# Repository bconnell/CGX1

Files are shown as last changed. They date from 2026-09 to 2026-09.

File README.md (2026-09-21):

<div align="center">

# CGX 1

### Compact GPU Engineering Design

**167.5 mm card length · 72 GB HBM4 baseline · 6.6 TB/s target bandwidth · 143.36 TFLOPS target · 360 W dock mode**

[Engineering Specification](docs/ENGINEERING_SPEC.md) · [ISA](docs/ISA.md) · [Graphics Pipeline](docs/GRAPHICS_PIPELINE.md) · [Documentation Index](docs/README.md) · [Validation](docs/VALIDATION.md)

**Design Engineer:** [Brandon Connell](https://github.com/bconnell) · [LinkedIn](https://www.linkedin.com/in/brandon-c-b317a81b/) · [Email](mailto:brandon@brandonconnell.com)  
Copyright © 2026 Brandon Connell · [MIT License](LICENSE)

</div>

CGX 1 is a compact desktop GPU architecture built around a low profile, dual slot card and an external power and thermal dock. The design targets graphics, game development, 3D work, media processing, compute, and local AI workloads while remaining usable in hosts that cannot supply or remove full GPU power internally.

> **Current status:** Engineering architecture and prototype design. No CGX 1 ASIC has been fabricated. Target values are analytical design values unless a document explicitly identifies measured prototype data. See [Project Status](docs/STATUS.md).

> **Repository policy:** CGX 1 is published as a public engineering reference. This repository does **not** accept pull requests, issues, discussions, external patches, or other community contributions. The MIT license permits independent forks and derivative work, but those remain separate projects unless Brandon Connell explicitly incorporates a change. For work inquiries or a serious private security concern, use the contact information in [AUTHORS.md](AUTHORS.md).

CGX 1 mechanical blueprint

[Open the mechanical blueprint directly](mechanical/cgx1_blueprint.svg)

## Design at a glance

| Parameter | Target | Design intent |
|---|---:|---|
| Card PCB | **167.5 × 68.5 mm** | Short, low profile board for compact desktop chassis |
| Installed thickness | **39.5 mm, dual slot** | Keep the installed card inside a conventional dual slot envelope |
| Baseline memory | **72 GB HBM4** | Two 36 GB stacks adjacent to the processor package |
| Peak memory bandwidth | **6.6 TB/s** | Aggregate architecture target from two 3.3 TB/s stacks |
| Peak FP32 | **143.36 TFLOPS** | Arithmetic target from lane count and 2.80 GHz peak clock |
| Full performance power | **360 W nominal** | External power and liquid cooling required |
| Standalone slot mode | **≤ 70 W** | Reduced operation without the external dock |
| Docked host slot draw | **≤ 25 W** | Keep high power demand off the host PSU |
| External supply | **48 V DC** | Certified AC/DC supply remains outside the coolant dock |
| PCIe target | **Gen 6 ×16** | Backward interoperability target through earlier PCIe generations |
| Dock envelope | **310 × 210 × 75 mm** | Sized around an actual 240 mm radiator, fans, pump/reservoir, fittings, and control hardware |

## Architecture

CGX 1 separates the compact add in card from the equipment needed for sustained high power operation. The card can boot and operate from the PCIe slot at a reduced power level. Full performance mode uses a rear connected 48 V power and liquid cooling dock, while mains conversion stays in a separate certified AC/DC supply.

```mermaid
flowchart LR
    AC[AC mains] --> PSU[Certified 48 V DC supply]
    PSU --> X[CGX 1 thermal dock]
    H[Host system] -->|PCIe x16| C[CGX 1 card]
    X -->|48 V + coolant| C
    C --> M[72 GB HBM4]
    C --> D[Display and media I/O]
```

The silicon target uses four compute tiles, a central I/O and cache die, two 36 GB HBM4 stacks, and a package level cache. The dock moves the radiator, pump, reservoir, and most full load heat rejection outside the host chassis.

## Operating modes

| Mode | Board limit | Host slot behavior | Use |
|---|---:|---:|---|
| **P0 Safe Boot** | 25 W | Up to 25 W | Reset, diagnostics, unknown host state, dock fault fallback |
| **P1 Slot Eco** | 45 W | Up to 45 W | Reduced slot powered operation on a qualified host |
| **P2 Slot Max** | 70 W | Up to 70 W | Maximum slot powered operation on a qualified host |
| **P3 Dock Quiet** | 220 W | ≤ 25 W | Development, capture, and moderate rendering |
| **P4 Dock Full** | 360 W | ≤ 25 W | Full design power target |
| **Transient ceiling** | 450 W | External path | Short electrical excursions, not sustained operation |

If dock power or valid coolant flow is lost in P3 or P4, the reference controller returns to **P0 Safe Boot** rather than increasing host slot demand.

## Primary design specification

[design/cgx1_architecture.json](design/cgx1_architecture.json) is the primary machine readable file for shared numeric targets. The repository validation scripts check important values mirrored in documentation, CAD, firmware, and the analytical model.

| Item | CGX 1 target | Notes |
|---|---:|---|
| Compute tiles | 4 | Separate graphics/compute tiles around the central I/O die |
| Compute units | 200 | 50 per tile |
| FP32 lanes | 25,600 | 128 per compute unit |
| Sustained clock target | 2.65 GHz | Full load design target |
| Peak clock target | 2.80 GHz | Used for peak FP32 arithmetic |
| Peak FP32 target | 143.36 TFLOPS | Not a measured benchmark |
| VRAM baseline | 72 GB HBM4 | Two 36 GB stacks |
| Future memory target | 96 GB HBM4 | Two 48 GB stacks if package and supply constraints permit |
| Package level cache target | 512 MB | Architecture target |
| Display target | 3 × Mini DisplayPort 2.1b + USB C DisplayPort Alt Mode | Final PHY and compliance work remains |
| Media target | 4 encode + 4 decode engines, AV1 | Architecture target |

## Architecture definition

The critical software-visible and multi-tile contracts are now defined rather than left to later RTL work:

| Area | Current architecture decision | Document |
|---|---|---|
| Execution | Native wave32; four SIMD32 partitions per CU; 32-bit base ISA with extension word | [ISA](docs/ISA.md) |
| Matrix engines | Four engines per CU; wave32; M16N16K16 FP16/BF16 and M16N16K32 FP8/INT8; fixed fragment map, 16-cycle issue target, staging/scoreboard RTL, signed INT8 arithmetic, integrated INT8 path, and a single-engine INT8 RTL shell | [Matrix Engine Architecture](docs/MATRIX_ENGINE.md) |
| Graphics | One logical GPU; 16 raster partitions; dynamic 32 × 32 pixel macro-tile ownership | [Graphics Pipeline](docs/GRAPHICS_PIPELINE.md) |
| Texture | 100 texture blocks; four bilinear samples/block/cycle arithmetic target | [Texture and Compression](docs/TEXTURE_COMPRESSION.md) |
| Compression | Lossless 256-byte surface blocks; no guaranteed compression ratio | [Texture and Compression](docs/TEXTURE_COMPRESSION.md) |
| Chiplet fabric | Central coherent I/O die; directory coherence; 7.2 TB/s aggregate read payload budget | [Chiplet Fabric](docs/CHIPLET_FABRIC.md) |
| Virtual memory | 57-bit GPU VA; 4 KiB/64 KiB/2 MiB pages; replayable faults; ATS/PASID optional | [Virtual Memory](docs/VIRTUAL_MEMORY.md) |
| Scheduling | 64 resident hardware queue contexts; 8 priorities; bounded preemption/reset escalation | [Scheduling and Preemption](docs/SCHEDULING_PREEMPTION.md) |
| Power management | Per-tile DVFS/power gating policy inside unchanged P0-P4 board limits; no fixed tile count per P-state | [Power Management](docs/POWER_MANAGEMENT.md) |

These values are design targets. They do not represent fabricated silicon capability or measured application performance.

## Prototype path

The first physical prototype does not require custom GPU silicon. **P0** is a dimensionally accurate electrothermal card and external dock used to validate fit, power distribution, coolant routing, control firmware, and a 360 W thermal load. **P1** adds a shared programmable HBM accelerator to the bench for PCIe, memory traffic, control, and software experiments.

| Stage | Hardware | What it establishes |
|---|---|---|
| **P0** | Card carrier, heaters, controller, cold plate, dock, instrumentation | Mechanical fit, 48 V delivery, cooling behavior, fault handling, firmware states |
| **P1** | P0 infrastructure plus an HBM capable programmable accelerator | PCIe behavior, memory traffic, host communication, selected RTL and software experiments |
| **Custom silicon** | Fabricated package and production class board | Device functionality, drivers, conformance, characterization, measured application performance |

See [Prototype Build](docs/PROTOTYPE_BUILD.md), [Mechanical Design](docs/MECHANICAL_DESIGN.md), and [Electrical Interface](docs/ELECTRICAL_INTERFACE.md).

## Documentation

The complete engineering document set is listed in the [Documentation Index](docs/README.md).

| Document | What it contains | Link |
|---|---|---|
| Engineering Specification | Card, package, silicon, memory, power, display, media, reliability | [Open](docs/ENGINEERING_SPEC.md) |
| ISA and Execution Model | Wave model, registers, instruction classes, memory ordering and faults | [Open](docs/ISA.md) |
| Matrix Engine Architecture | Numeric contract, physical tile shapes, wave32 fragment mapping, ISA opcodes, banking, operand staging, per-wave scoreboard, pipeline timing, and dense rate targets | [Open](docs/MATRIX_ENGINE.md) |
| Graphics Pipeline | Multi-tile geometry, raster, ownership, depth and presentation flow | [Open](docs/GRAPHICS_PIPELINE.md) |
| Texture and Compression | Sampler organization and lossless surface compression | [Open](docs/TEXTURE_COMPRESSION.md) |
| Chiplet Fabric | Tile links, coherence, bandwidth budget, reliability and QoS | [Open](docs/CHIPLET_FABRIC.md) |
| Virtual Memory | GPU address spaces, pages, faults, residency, ATS/PASID integration | [Open](docs/VIRTUAL_MEMORY.md) |
| Scheduling and Preemption | Queue model, priorities, preemption and reset containment | [Open](docs/SCHEDULING_PREEMPTION.md) |
| Power Management | Per-tile DVFS, gating, board-budget enforcement and safe transition ordering | [Open](docs/POWER_MANAGEMENT.md) |
| Project Status | What is implemented, modeled, planned, or not yet built | [Open](docs/STATUS.md) |
| Mechanical Design | Card and dock dimensions, selected prototype components, packing assumptions | [Open](docs/MECHANICAL_DESIGN.md) |
| Electrical Interface | Slot power, 48 V input, isolation, fallback behavior, interlocks | [Open](docs/ELECTRICAL_INTERFACE.md) |
| Thermal and Power | 360 W budget, coolant arithmetic, thermal assumptions | [Open](docs/THERMAL_POWER.md) |
| Prototype Build | P0 and P1 construction and acceptance work | [Open](docs/PROTOTYPE_BUILD.md) |
| Prototype Procurement | Consumables, equipment, prices, exact parts, substitutes | [Open](docs/PROTOTYPE_PROCUREMENT.md) |
| Prototype Unit Cost | Per unit planning after bench equipment is owned | [Open](docs/PROTOTYPE_UNIT_COST.md) |
| Software Stack | Firmware, kernel, graphics, compute, media, compiler, and diagnostics plan | [Open](docs/SOFTWARE_STACK.md) |
| Validation | Repository, model, firmware, mechanical, P0, P1, and future silicon checks | [Open](docs/VALIDATION.md) |
| Test Record Template | Standard fields for measured prototype test records | [Open](docs/TEST_RECORD_TEMPLATE.md) |
| Reference Comparison | Dated comparison against shipping reference GPUs | [Open](docs/REFERENCE_COMPARISON.md) |
| Sources | Public technical and procurement references | [Open](docs/SOURCES.md) |
| Roadmap | Remaining prototype and silicon work | [Open](docs/ROADMAP.md) |

## Build and test

A standard CMake toolchain is sufficient for the current analytical model, ISA reference tests, matrix numeric, physical-architecture, register-interface, banking, staging, scoreboard, INT8 arithmetic, INT8 path integration, and INT8 engine-shell tests, power-management policy tests, and firmware tests.

```text
cmake -S . -B build
cmake --build build --config Release
ctest --test-dir build --output-on-failure -C Release
```

Matrix pipeline control RTL has a separate simulator gate:

~~~bash
./scripts/validate_rtl.sh
~~~

It requires Icarus Verilog. The workflow installs Icarus on Ubuntu and runs only when RTL or its matrix architecture inputs change.

The complete Windows repository gate can be run locally with:

```powershell
.\scripts\validate_windows.ps1
```

The gate checks public wording, private and local residue, PowerShell parsing, design consistency, local Markdown links, the C and C++ build, negative controls, and the executable tests.

## Reference comparison

The dated comparison uses NVIDIA RTX PRO 6000 Blackwell Workstation Edition as the primary workstation reference and GeForce RTX 5090 as a gaming reference. CGX figures remain architecture targets. Shipping product specifications are kept separate from analytical CGX values and measured performance is not inferred from arithmetic throughput.

See [Reference GPU Comparison](docs/REFERENCE_COMPARISON.md).

## License and contact

CGX 1 is released under the [MIT License](LICENSE).

**Design Engineer:** [Brandon Connell](https://github.com/bconnell)  
**Work contact:** [brandon@brandonconnell.com](mailto:brandon@brandonconnell.com)  
**LinkedIn:** [Brandon Connell](https://www.linkedin.com/in/brandon-c-b317a81b/)  
**Copyright:** © 2026 Brandon Connell

The copyright notice is carried in [LICENSE](LICENSE). Work contact information is also carried in [AUTHORS.md](AUTHORS.md), [NOTICE.md](NOTICE.md), and [CITATION.cff](CITATION.cff) so it remains easy to find in redistributed source packages.

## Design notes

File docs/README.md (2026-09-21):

# CGX 1 Documentation

[Repository home](../README.md) · [Design authorship](../AUTHORS.md) · [License](../LICENSE) · [Sources](SOURCES.md)

This directory contains the public engineering documentation for CGX 1. The documents are separated by subsystem so specifications, prototype instructions, procurement, validation, and future work do not get mixed together.

## Core design documents

| Document | Scope | Start here when |
|---|---|---|
| [Engineering Specification](ENGINEERING_SPEC.md) | Card, package, compute, memory, I/O, power, display, media, reliability | You need the complete architecture |
| [Project Status](STATUS.md) | Implemented files, executable references, prototype state, missing production work | You need to know what physically exists |
| [Mechanical Design](MECHANICAL_DESIGN.md) | Card and dock envelopes, component packing, selected fans, radiator, pump/reservoir | You are building or checking fit |
| [Electrical Interface](ELECTRICAL_INTERFACE.md) | PCIe slot power, external 48 V path, isolation, interlocks, fault fallback | You are designing power or control hardware |
| [Thermal and Power Design](THERMAL_POWER.md) | Full power budget, coolant calculation, thermal targets | You are sizing cooling or power delivery |
| [Architecture BOM](BOM.md) | Package, PCB, power, cooling, I/O requirements | You are translating architecture into hardware |

## Architecture definition

| Document | Scope | Start here when |
|---|---|---|
| [ISA and Execution Model](ISA.md) | Native wave model, registers, instruction encoding, ordering, faults | You are writing RTL, an assembler, compiler or debugger |
| [Matrix Engine Architecture](MATRIX_ENGINE.md) | Numeric behavior, M16N16 tile shapes, wave32 fragment mapping, Matrix opcodes, register-interface schedule, input/output staging, modulo-8 bank classes, per-wave scoreboard behavior, signed INT8 arithmetic/path integration and one-wave engine shell, pipeline timing, reduction order, and dense-rate targets | You are implementing matrix RTL, compiler lowering or API exposure |
| [Graphics Pipeline](GRAPHICS_PIPELINE.md) | Multi-tile geometry, rasterization, render ownership, depth and presentation | You are implementing the graphics front/back end |
| [Texture and Compression](TEXTURE_COMPRESSION.md) | Samplers, filtering, format decode and lossless surface compression | You are implementing texture or memory-bandwidth logic |
| [Chiplet Fabric](CHIPLET_FABRIC.md) | Tile topology, coherence, bandwidth budget, reliability and QoS | You are designing package links or cache coherence |
| [Virtual Memory](VIRTUAL_MEMORY.md) | GPU address spaces, page tables, faults, residency and optional ATS/PASID | You are implementing memory management |
| [Scheduling and Preemption](SCHEDULING_PREEMPTION.md) | Hardware queues, priorities, preemption, watchdog and reset domains | You are implementing command processing or recovery |
| [Power Management](POWER_MANAGEMENT.md) | Per-tile DVFS, gating, board budgets, transitions and fault isolation | You are implementing tile power policy or controller logic |

## Prototype documents

| Document | Scope | Start here when |
|---|---|---|
| [Prototype Build](PROTOTYPE_BUILD.md) | P0 electrothermal build and P1 programmable bench | You are assembling the first hardware |
| [Prototype Procurement](PROTOTYPE_PROCUREMENT.md) | Exact parts, consumables, bench tools, alternatives, price snapshots | You are purchasing equipment or parts |
| [Prototype Unit Cost](PROTOTYPE_UNIT_COST.md) | Recurring prototype cost after tools are already owned | You are estimating per unit expense |
| [Test Record Template](TEST_RECORD_TEMPLATE.md) | Fields for measured prototype results | You are recording P0 or P1 data |
| [Host Compatibility](HOST_COMPATIBILITY.md) | Generic compact and tower host requirements | You are checking a chassis or motherboard |

## Software and validation

| Document | Scope | Start here when |
|---|---|---|
| [Software Stack](SOFTWARE_STACK.md) | Firmware, Linux, Windows, Vulkan, Direct3D, media, compiler, diagnostics | You are working on host software or drivers |
| [Validation](VALIDATION.md) | Repository, analytical, firmware, mechanical, prototype, and future silicon checks | You need acceptance criteria |
| [Repository Integrity](REPOSITORY_INTEGRITY.md) | Public hygiene, secrets, build output, consistency and negative controls | You are changing repository infrastructure |
| [Documentation Style](DOCUMENTATION_STYLE.md) | Public technical writing conventions | You are editing public documentation |
| [Artifact Provenance](ARTIFACT_PROVENANCE.md) | Which files are authoritative, derived, or manually maintained | You are regenerating design files |

## Reference material and future work

| Document | Scope | Start here when |
|---|---|---|
| [Reference GPU Comparison](REFERENCE_COMPARISON.md) | Dated CGX target comparison with shipping GPUs | You want a current side by side reference |
| [Public Sources](SOURCES.md) | Manufacturer, standards, process, and procurement sources | You need to verify an external fact |
| [Build Instructions](BUILD_INSTRUCTIONS.md) | Long path from architecture through ASIC, board, drivers, and qualification | You are planning beyond P0/P1 |
| [Roadmap](ROADMAP.md) | Remaining mechanical, electrical, software, prototype, and silicon work | You want the work sequence |

## Primary machine readable design file

Shared numeric targets are maintained in [`design/cgx1_architecture.json`](../design/cgx1_architecture.json). Human readable documents explain those values and their engineering context.

If a document and the machine readable file disagree on a shared target, treat the mismatch as a repository defect and fix both the value and the consistency test.

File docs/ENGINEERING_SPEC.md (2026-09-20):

# CGX 1 Engineering Specification

[Documentation index](README.md) · [Project status](STATUS.md) · [Mechanical design](MECHANICAL_DESIGN.md) · [Electrical interface](ELECTRICAL_INTERFACE.md) · [Software stack](SOFTWARE_STACK.md)

## 1. Design objective

CGX 1 targets high compute and memory throughput in a low profile PCIe add in card. The architecture separates the card envelope from bulk power delivery and full load heat rejection. Full power arrives from an external 48 V source and the liquid loop transports most full load heat to an external thermal dock.

The design covers two broad host classes:

- low profile OEM desktops where internal power and cooling are limited;
- compact and conventional tower systems where a short card and independent power path improve installation flexibility.

Exact chassis fit depends on physical clearance, slot geometry, firmware behavior, and the host PCIe implementation.

## 2. Mechanical architecture

### 2.1 Card envelope

| Parameter | Target | Notes |
|---|---:|---|
| PCB | 167.5 × 68.5 mm | Low profile board target |
| Installed thickness | 39.5 mm | Dual slot envelope |
| Bracket | Low profile or full height | Replaceable two slot metalwork |
| Package target | ≤ 55 × 55 mm | Compute, I/O, cache, HBM package region |
| Card fans | 2 × 50 × 50 × 10 mm | Same Sky CFM-5010B-170-361-22 reference |

High current power and coolant services exit at the rear bracket. The primary package region is kept close to the slot support region to reduce board bending moment.

The card CAD and selected fan reference are documented in [Mechanical Design](MECHANICAL_DESIGN.md).

### 2.2 External thermal dock

The dock contains the low voltage cooling and monitoring hardware. Mains conversion remains in a separate certified 48 V AC/DC supply.

| Parameter | Target/reference | Notes |
|---|---:|---|
| Dock outer envelope | 310 × 210 × 75 mm | Revised from the earlier undersized envelope |
| Radiator | Corsair XR5 240 | 280 × 120 × 30 mm |
| Radiator fans | 2 × 120 × 120 × 25 mm class | Pressure oriented PWM fans |
| Pump/reservoir | Alphacool ES Reservoir DDCzero 1U, part 14571 | 112 × 57 × 41.95 mm |
| Nominal coolant flow | 1.5 L/min | Thermal analysis point |
| Quick disconnects | Dry break | Supply and return |

The revised dock dimensions leave separate volumes for the 55 mm radiator/fan stack and the pump/reservoir, plus enclosure walls, fittings, wiring, sensors, and service clearance.

See [Mechanical Design](MECHANICAL_DESIGN.md).

## 3. Silicon architecture

### 3.1 Process and package

The preferred first implementation process is TSMC N2P. TSMC A16 remains a later process option. TSMC states that N2P and A16 volume production is scheduled for the second half of 2026, with A16 using backside power delivery for dense HPC designs. See [Public Sources](SOURCES.md).

The package target contains:

- four graphics compute tiles;
- one central I/O, display, media, security, fabric, and cache controller die;
- two 36 GB HBM4 stacks;
- a 512 MB package level stacked SRAM cache target;
- a silicon interposer or equivalent advanced package substrate.

Nominal package envelope target: no larger than 55 × 55 mm.

### 3.2 Compute organization

| Item | Target | Derivation or purpose |
|---|---:|---|
| Compute tiles | 4 | Physical compute partition |
| Compute units per tile | 50 | 200 total |
| Compute units total | 200 | Architecture target |
| FP32 lanes per compute unit | 128 | 25,600 total |
| FP32 lanes total | 25,600 | Peak arithmetic input |
| Matrix engines per compute unit | 4 | One per SIMD32 partition; physical shape, mapping, instruction form, and issue model are defined architecture targets |
| Ray traversal/intersection engines per compute unit | 1 | Architecture target, throughput not yet frozen |
| ROPs | 256 | Architecture target |
| Sustained full clock | 2.65 GHz | Full load target |
| Peak clock | 2.80 GHz | Peak arithmetic target |

Peak FP32 arithmetic target:

```text
25,600 lanes × 2 operations/FMA × 2.80 GHz = 143.36 TFLOPS
```

This is a theoretical arithmetic target, not measured application performance.

Matrix-engine architecture targets are defined separately in [Matrix Engine Architecture](MATRIX_ENGINE.md). FP16/BF16 use M16N16K16 tiles; FP8/INT8 use M16N16K32 tiles. With a 16-cycle per-engine issue interval, the derived dense peak-clock targets are 1,146.88 TFLOPS for FP16/BF16 and 2,293.76 TFLOPS/TOPS for FP8/INT8. These are architectural arithmetic targets, not measured silicon or application results.

### 3.3 Cache hierarchy

- 128 KB combined L1/shared memory per compute unit target.
- 16 MB L2 slice per compute tile.
- 64 MB aggregate L2 target.
- 512 MB package level stacked SRAM victim/cache layer target.

The package level cache is intended to reduce HBM traffic and reduce sensitivity to older host PCIe links and systems without Resizable BAR.

### 3.4 Memory

- 2 × 36 GB HBM4 baseline.
- 72 GB baseline VRAM.
- Up to 3.3 TB/s target per stack.
- Up to 6.6 TB/s aggregate peak target.
- ECC enabled by default for development and compute use.
- 96 GB remains a future capacity target if two 48 GB HBM4 stacks satisfy package, thermal, supply, and controller requirements.

Samsung currently publishes HBM4 capacities through 36 GB on 12 layers at up to 3.3 TB/s per stack, with 16 layer configurations extending to 48 GB. See [Public Sources](SOURCES.md).

### 3.5 Execution model

Each compute unit contains four SIMD32 partitions, giving the existing 128 FP32 lanes per CU. Native wave size is 32 lanes. The first instruction contract uses a 32-bit base word and an optional 32-bit extension word.

The dedicated matrix-engine target uses wave32 cooperative execution with FP16, BF16, OCP FP8 E4M3/E5M2, and signed INT8 baseline profiles. Floating profiles accumulate to FP32; signed INT8 accumulates to signed INT32. Physical matrix tile dimensions, issue rate, and throughput remain unfrozen.

See [ISA and Execution Model](ISA.md) and [Matrix Engine Architecture](MATRIX_ENGINE.md).

### 3.6 Graphics and texture organization

The four compute tiles form one logical GPU. Each tile targets 25 texture blocks, four raster partitions and 64 color/depth result lanes. Render work uses dynamic 32 × 32 pixel macro-tile ownership so ordered render-target updates can remain local to one tile while active.

The texture target is 100 blocks total at four bilinear sample results per block per cycle under the simple cache-resident arithmetic case. At 2.80 GHz this is a 1,120 Gsamples/s arithmetic ceiling, not a guaranteed application rate.

See [Graphics Pipeline](GRAPHICS_PIPELINE.md) and [Texture and Compression](TEXTURE_COMPRESSION.md).

### 3.7 Chiplet fabric

The central I/O/cache die maintains directory coherence across four write-back tile L2 caches. Aggregate tile read payload budget is 7.2 TB/s so the fabric target does not undercut the 6.6 TB/s HBM4 peak before cache effects.

UCIe 3.0 is the preferred die-to-die PHY/management reference. UCIe compliance and physical lane counts are not currently claimed.

See [Chiplet Fabric](CHIPLET_FABRIC.md).

### 3.8 Virtual memory

The architecture targets 57-bit GPU virtual addresses, 4 KiB/64 KiB/2 MiB pages, 64 KiB preferred VRAM pages and replayable page faults. PCIe ATS, PRI and PASID are optional host accelerators; basic operation does not require them.

See [Virtual Memory](VIRTUAL_MEMORY.md).

### 3.9 Scheduling and preemption

The first scheduler target provides 64 resident hardware queue contexts, eight priorities, power-aware placement and weighted fair scheduling with aging. Mandatory preemption is workgroup-boundary for compute and draw/dispatch-packet boundary for graphics. Recovery escalates engine, tile, then device reset.

See [Scheduling and Preemption](SCHEDULING_PREEMPTION.md).

## 4. Host interface

### 4.1 PCIe

- Native target: PCIe Gen 6 ×16.
- Backward interoperability target through earlier PCIe generations.
- Non Resizable BAR support through a bounded aperture and command buffer paging design.
- Local VRAM and package cache reduce dependence on host link bandwidth.

PCI SIG states that PCIe 6.0 maintains backward compatibility with previous PCIe generations. Final card compliance still requires the complete electrical and protocol implementation.

### 4.2 Boot behavior

The card enters P0 Safe Boot after reset. Early firmware reads:

- negotiated PCIe generation and width;
- host firmware capabilities;
- external 48 V presence;
- coolant flow and temperature sensors;
- slot voltage and current telemetry.

The card cannot enter P3 or P4 when required dock conditions are absent.

## 5. Power states

| State | Board limit | Host slot limit | Behavior |
|---|---:|---:|---|
| P0 Safe Boot | 25 W | 25 W | Reset, diagnostics, unknown host, fault fallback |
| P1 Slot Eco | 45 W | 45 W | Qualified reduced slot operation |
| P2 Slot Max | 70 W | 70 W | Qualified maximum slot operation |
| P3 Dock Quiet | 220 W | 25 W | External 48 V and valid coolant flow required |
| P4 Dock Full | 360 W | 25 W | External 48 V and valid coolant flow required |
| Electrical transient ceiling | 450 W | External path | Short electrical excursion only |

If external 48 V or valid coolant flow is lost in P3/P4, the reference controller returns to P0 at 25 W. This avoids increasing motherboard slot demand during a dock fault.

See [Electrical Interface](ELECTRICAL_INTERFACE.md).

### 5.1 Internal power management

P0-P4 remain board-level electrical and safety envelopes. They do not prescribe a fixed active compute-tile count.

The I/O-die power-management controller targets independent per-tile DVFS, clock gating, and whole-tile retention/off states inside the active P-state budget. The scheduler uses a power-manager eligibility mask rather than manipulating rails directly.

Exact tile voltage/frequency points are not frozen. The architecture retains the 0.55 V to 0.90 V GPU-core target range and the 2.65/2.80 GHz clock targets, but a real V/F curve requires physical timing, power, process, and silicon characterization.

See [Power Management](POWER_MANAGEMENT.md).

## 6. Voltage regulation

The high power input uses 48 V to reduce cable current. A separate certified AC/DC supply creates the 48 V rail. The thermal dock handles low voltage distribution and monitoring. The card uses intermediate conversion followed by point of load rails.

Principal target rails:

- GPU core: 0.55 V to 0.90 V adaptive;
- SRAM/cache: 0.65 V to 0.90 V;
- HBM rails per memory vendor specification;
- 1.8 V, 3.3 V, and auxiliary I/O/control rails.

Power conversion targets:

- at least 94 percent weighted conversion efficiency in P4;
- telemetry on every major rail;
- independent over current and over voltage protection;
- slot and external inputs isolated against backfeed.

## 7. Display and media

Display target:

- 3 × Mini DisplayPort 2.1b;
- 1 × USB C DisplayPort Alt Mode output;
- HDR and modern variable refresh support in the eventual display stack.

Media target:

- four hardware encode engines;
- four hardware decode engines;
- AV1 encode and decode as a primary format;
- H.264 and HEVC compatibility;
- low latency capture path suitable for game recording and streaming software.

## 8. Software implementation

A complete device requires firmware, kernel drivers, user mode graphics and compute drivers, shader compiler support, media integration, diagnostics, and application conformance work.

Planned implementation order:

1. firmware and board management;
2. Linux allocation, reset, interrupt, and display basics;
3. Vulkan compute;
4. basic Vulkan graphics;
5. shader compiler and conformance expansion;
6. ray tracing and advanced graphics features;
7. media APIs;
8. Windows display and compute stack;
9. native Direct3D 12 support.

CUDA compatibility is not claimed.

The software plan is expanded in [Software Stack](SOFTWARE_STACK.md).

## 9. Reliability and serviceability

- Hardware fault logic must be able to reduce power without normal GPU firmware execution.
- Dock loss or invalid flow in P3/P4 returns the reference controller to P0.
- Power, temperature, flow, and fault telemetry must be exposed to firmware and diagnostics.
- The thermal dock is serviceable independently of the card.
- The cold plate, pump/reservoir, fans, and quick disconnect hardware should be replaceable without replacing the compute board.

## 10. Production work still required

A tapeout capable implementation still requires full compute and graphics RTL, verified HBM and PCIe PHY integration, foundry PDK work, DFT, physical design, timing closure, IR/EM signoff, DRC/LVS, package simulation, signal integrity, power integrity, thermal simulation, masks, silicon validation, manufacturing test development, driver development, and application qualification.

See [Build Instructions](BUILD_INSTRUCTIONS.md) and [Roadmap](ROADMAP.md).

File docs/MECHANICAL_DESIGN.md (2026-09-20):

# Mechanical Design

[Documentation index](README.md) · [Engineering specification](ENGINEERING_SPEC.md) · [Thermal and power](THERMAL_POWER.md) · [Prototype build](PROTOTYPE_BUILD.md)

## Card envelope

The card target remains **167.5 × 68.5 × 39.5 mm** outside the replaceable rear bracket hardware.

| Feature | Target | Prototype reference |
|---|---:|---|
| PCB length | 167.5 mm | Short card target |
| PCB height | 68.5 mm | Low profile board target |
| Installed thickness | 39.5 mm | Dual slot envelope |
| Package keepout | ≤ 55 × 55 mm | Compute + I/O + HBM package region |
| Card fans | 2 × 50 mm | Same Sky CFM-5010B-170-361-22 |
| Fan thickness | 10 mm | Manufacturer published dimension |
| Fan voltage | 12 V | PWM and tachometer capable |

The OpenSCAD model uses the selected fan thickness. The fin envelope is reduced accordingly so the complete card remains within 39.5 mm.

The 50 mm reference fan is an active Same Sky part, model **CFM-5010B-170-361-22**, specified as a 50 mm square, 10 mm thick, 12 V PWM/tachometer fan. See [Public Sources](SOURCES.md).

## Rear bracket services

The bracket concept provides:

- three Mini DisplayPort 2.1b target openings;
- one USB C DisplayPort Alt Mode target opening;
- coolant supply and return service;
- external 48 V service connection;
- interchangeable low profile and full height metalwork.

The exact connector mechanicals remain a board design task. The current SVG blueprint is a layout target, not a released sheet metal drawing.

## External thermal dock

The revised dock target is **310 × 210 × 75 mm**.

The enclosure is sized around the published dimensions of the radiator, radiator fans, and pump/reservoir, with additional volume reserved for fittings, low voltage control hardware, wiring, enclosure walls, and service routing.

### Packing references

| Component | Published size | Placement assumption |
|---|---:|---|
| Corsair XR5 240 radiator | 280 × 120 × 30 mm | Main radiator bay |
| Two 120 mm radiator fans | 120 × 120 × 25 mm each | Stacked on radiator, 55 mm radiator/fan thickness |
| Alphacool ES Reservoir DDCzero 1U with Pump, part 14571 | 112 × 57 × 41.95 mm | Alongside the radiator bay |
| Dock outer envelope | 310 × 210 × 75 mm | Allows enclosure walls, component clearance, fittings, wiring, and airflow openings |

The dock OpenSCAD source models those reference volumes directly. It is intentionally simple enough to expose interference instead of hiding it behind cosmetic geometry.

## Power supply location

The AC/DC power supply is **not inside the thermal dock**.

The electrical arrangement is:

```text
AC mains
   |
certified 48 V AC/DC supply
   |
CGX 1 thermal dock
   |
48 V + coolant
   |
CGX 1 card
```

Keeping mains conversion outside the coolant enclosure reduces dock packing pressure and keeps line voltage away from the pump, reservoir, coolant fittings, and prototype control electronics.

## Mechanical acceptance checks

Before P0 is accepted:

1. measure the finished card length, height, and thickness;
2. confirm both bracket variants fit their intended slot geometry;
3. confirm both 50 mm fans fit without exceeding 39.5 mm installed thickness;
4. confirm the 280 mm radiator and both 120 mm fans fit the dock;
5. confirm the pump/reservoir volume fits without intersecting the radiator or fan volumes;
6. confirm fitting and hose bend clearance with the enclosure closed;
7. confirm the 48 V and coolant services exit without requiring hidden side clearance;
8. inspect mounting pressure and PCB bending;
9. pressure test and leak test the coolant assembly before powered electronics are installed.

## Source files

- [Card OpenSCAD source](../mechanical/cgx1_card.scad)
- [Dock OpenSCAD source](../mechanical/cgx1_dock.scad)
- [Mechanical blueprint](../mechanical/cgx1_blueprint.svg)
- [Card STL envelope](../mechanical/cgx1_card.stl)
- [Dock STL envelope](../mechanical/cgx1_dock.stl)

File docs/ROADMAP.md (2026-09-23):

# Roadmap

[Documentation index](README.md) · [Project status](STATUS.md) · [Prototype build](PROTOTYPE_BUILD.md)

## Current design package

- architecture specification and machine readable target file;
- revised card and thermal dock envelopes;
- selected prototype fan, radiator, and pump/reservoir references;
- analytical thermal, power, fit, and FP32 model;
- reference power state firmware;
- top level RTL state scaffold;
- prototype procurement and cost planning;
- software implementation plan;
- native wave32 ISA and executable base instruction encoder/decoder;
- matrix-engine numeric contract, M16N16 physical tile definitions, wave32 fragment map, base ISA opcodes, pipeline timing target, dense-rate derivation, executable register-interface schedule, and exhaustive modulo-8 bank-conflict reference;
- multi-tile graphics pipeline and render ownership model;
- texture block and lossless surface-compression architecture;
- coherent chiplet-fabric protocol and bandwidth budget;
- virtual-memory/page-fault architecture;
- queue scheduling, preemption and reset containment model;
- per-tile DVFS, clock/power-gating architecture and executable policy/invariant model;
- validation and repository integrity checks.

## P0 manufacturing package

- dimensioned heater locations matching planned package heat regions;
- copper spreader and cold plate machining drawing;
- rear power and coolant connector drawing;
- low profile and full height bracket drawings;
- detailed dock internal arrangement and hose/fitting clearance;
- 48 V low voltage harness drawing;
- control PCB schematic;
- control PCB layout, drill files, and manufacturing outputs;
- instrumented 360 W thermal procedure.

## P0 physical validation

- fabricate card carrier and revised dock;
- validate selected 50 mm fan fit;
- validate radiator, radiator fans, and pump/reservoir packing;
- validate actual loop flow;
- validate coolant rise and component temperatures;
- validate connector heating and 48 V delivery;
- validate P3/P4 dock loss fallback to P0;
- measure card and dock dimensions;
- revise mechanical and thermal targets from measured results.

## P1 programmable bench

- integrate one shared HBM programmable accelerator;
- prototype command, telemetry, memory movement, and selected RTL blocks;
- establish reproducible host software tests;
- keep surrogate results labeled as surrogate measurements.

## Architecture implementation

- implement the complete ISA semantics and assembler/disassembler;
- build an instruction-level emulator and shader execution tests;
- implement command processor and queue packet ABI;
- implement page tables, translation caches and replayable-fault model;
- implement tile coherence protocol and fabric transaction model;
- implement texture sampling and compression reference models;
- implement primitive binning, raster ownership and back-end ordering models;
- obtain exact-revision RTL simulation evidence for the pooled resident-wave VGPR, ordinary/shared access, INT32 vector execution, resident vector scheduling, and unified matrix/vector/restore storage boundaries;
- obtain exact-revision simulation evidence for the published mixed resident INT8-matrix/INT32-vector execution frontend; then replace its external per-wave `vector_dependency_ready` contract with the canonical compute-unit scheduler/scoreboard dependency source while keeping the mixed-workload service-window policy parameterized until scheduling evidence supports a value;
- select implementation storage macros without prematurely freezing resident-wave occupancy, implement FP16/BF16/FP8 matrix arithmetic with the frozen FP32-FMA semantics, and validate timing, area, and power; revise timing targets if physical evidence cannot close them;
- validate every advertised precision profile against the numeric and physical architecture references, then add compiler/API lowering;
- characterize finer-than-workgroup preemption cost before adding it to the baseline;
- characterize real per-tile V/F curves, leakage, transition latency, and controller hysteresis;
- implement and verify the I/O-die power manager, tile isolation, retention, clock gating, and power-gating RTL.

## Custom silicon

- implement the defined ISA and shader execution model in verified RTL and software;
- complete compute, raster, ray, cache, fabric, memory, display, media, security, and debug RTL;
- complete verification and FPGA/emulation work;
- select licensed PHY and codec IP;
- complete physical design and package engineering;
- fabricate validation silicon;
- develop Linux and Windows drivers;
- complete graphics, compute, media, and application conformance;
- characterize production silicon and publish measured performance separately from design targets.

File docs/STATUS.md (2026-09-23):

# Project Status

[Documentation index](README.md) · [Engineering specification](ENGINEERING_SPEC.md) · [Validation](VALIDATION.md) · [Roadmap](ROADMAP.md)

CGX 1 is an engineering architecture and prototype program. No custom CGX 1 ASIC has been fabricated.

## Current repository contents

| Area | Current state | Evidence in this repository |
|---|---|---|
| Architecture | Defined target | [Engineering Specification](ENGINEERING_SPEC.md) and [machine readable design file](../design/cgx1_architecture.json) |
| ISA/execution model | Defined architecture + executable base encoder/decoder | [ISA](ISA.md) and [source/isa](../source/isa/) |
| Matrix engine architecture | Defined numeric + physical execution contract with executable numeric, fragment, register-interface schedule, and bank-conflict references | [Matrix Engine Architecture](MATRIX_ENGINE.md) and [source/matrix](../source/matrix/) |
| Graphics pipeline | Defined architecture target | [Graphics Pipeline](GRAPHICS_PIPELINE.md) |
| Texture/compression | Defined architecture target | [Texture and Compression](TEXTURE_COMPRESSION.md) |
| Chiplet fabric/coherence | Defined architecture target; physical lane map not frozen | [Chiplet Fabric](CHIPLET_FABRIC.md) |
| Virtual memory | Defined architecture target | [Virtual Memory](VIRTUAL_MEMORY.md) |
| Scheduling/preemption | Defined architecture target | [Scheduling and Preemption](SCHEDULING_PREEMPTION.md) |
| Mechanical envelope | Defined target | OpenSCAD card/dock sources, SVG blueprint, STL envelope models, [Mechanical Design](MECHANICAL_DESIGN.md) |
| Analytical model | Executable | FP32 arithmetic, coolant rise, junction estimate, power efficiency, fit calculations |
| Power state controller | Executable reference | C implementation and fault state tests |
| Per-tile power management | Defined architecture + executable policy/invariant model | [Power Management](POWER_MANAGEMENT.md) and [source/power](../source/power/) |
| RTL | Limited control/storage/arithmetic RTL | Power-state/tile-enable scaffold, matrix control/staging, signed INT8 arithmetic/path, validated one-wave shell, plus parameterized resident-wave arbitration, wave-local dependency, scoreboard routing, and ordinary issue-admission RTL validated by the repository RTL simulation gate; FP16/BF16/FP8 arithmetic and physical implementation remain open |
| P0 electrothermal prototype | Planned build | [Prototype Build](PROTOTYPE_BUILD.md), [Procurement](PROTOTYPE_PROCUREMENT.md), [Test Record Template](TEST_RECORD_TEMPLATE.md) |
| P1 programmable surrogate | Planned bench work | AMD Alveo U50 class HBM accelerator reference |
| Custom PCB schematic/layout | Not implemented | Board constraints exist; schematic, layout, and manufacturing files remain open work |
| Custom ASIC | Not implemented | Production RTL, verification, physical design, package implementation, and tapeout remain open work |
| Graphics driver | Not implemented | [Software Stack](SOFTWARE_STACK.md) defines the planned implementation order |
| Measured CGX performance | None | No fabricated CGX silicon exists |

## Numeric target interpretation

**143.36 TFLOPS** is an arithmetic peak target derived from 25,600 FP32 lanes, two floating point operations per FMA, and a 2.80 GHz peak clock target.

**6.6 TB/s** is a memory architecture target based on two HBM4 stacks at up to 3.3 TB/s each. It is not a sustained application bandwidth measurement.

Thermal temperatures in this repository are analytical estimates until measured on P0 hardware.

Application performance, frame rate, renderer throughput, media speed, and local model inference performance require hardware and reproducible benchmark data. They are not derived from the analytical model.

Matrix tile shapes, fragment mapping, opcode assignments, per-engine issue interval, and theoretical dense arithmetic targets are frozen as architecture targets. The current peak-clock targets are 1,146.88 TFLOPS for FP16/BF16 and 2,293.76 TFLOPS/TOPS for FP8/INT8. These are not measured silicon results. The matrix register-interface schedule, modulo-8 bank-class conflict rules, pending-destination interlocks, capture-to-active operand staging, output-result staging, and per-wave ordinary VGPR hazard checks are executable and simulated where applicable. Signed INT8 functional arithmetic has passed the standalone RTL simulation gate. Capture/execute/result/writeback integration has also passed the repository RTL simulation gate, while FP16/BF16/FP8 arithmetic remains open. Resident-wave identity, wave-local matrix dependencies, round-robin request selection, per-wave scoreboard routing, and ordinary issue admission are implemented in the resident-engine RTL boundary and have passed the repository RTL simulation gate. The pooled-VGPR implementation now also has a published ordinary-vector path: exact-count ordinary reads/writes, serialized distinct same-bank source reads, a shared matrix/vector/restore port arbiter, release safety across both execution classes, a wave32 INT32 ADD/SUB/AND/OR/XOR/SHL/LSR/ASR pipeline, resident-wave round-robin vector selection, and matrix/vector hazard and issue guards. These new boundaries are wired into the repository executable and RTL gates, but exact-revision simulation evidence remains pending. The internal vector opcode encoding and mixed-workload admission policy are not frozen ISA commitments. Foundry storage-macro selection, full compute-unit integration, physical arithmetic organization, timing closure, area, and power remain unvalidated. No independent AI TOPS benchmark value or structured-sparsity multiplier is claimed.

A mixed resident execution frontend now composes the signed INT8 matrix engine and resident INT32 vector pipeline over the same unified pooled-VGPR authority. Legal matrix requests require pooled initialization/range preflight and clear live-vector dependency locks; malformed matrix requests still reach the existing controller-owned illegal path. The selected vector request remains gated by the matrix scoreboard, and one edge cannot accept both a matrix and vector instruction. The per-wave `vector_dependency_ready` input remains an explicit scheduler contract, so this is not yet the full compute-unit scheduler. Exact-revision RTL simulation evidence for this mixed frontend remains pending.

## Evidence labels used in this repository

| Label | Meaning | Example |
|---|---|---|
| **Target** | Intended design value | 360 W P4 board limit |
| **Analytical** | Result of equations or an executable analytical model | 3.45 °C coolant rise at the stated assumptions |
| **Prototype measured** | Instrumented P0 or P1 result | Future coolant inlet/outlet measurements |
| **Surrogate measured** | Result from non CGX programmable hardware | Future Alveo bench result |
| **Silicon measured** | Result from fabricated CGX hardware | Not available yet |

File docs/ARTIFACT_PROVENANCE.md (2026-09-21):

# Artifact Provenance

[Documentation index](README.md) · [Repository integrity](REPOSITORY_INTEGRITY.md)

The repository distinguishes editable engineering source from derived files.

| Artifact | Role | Maintenance rule |
|---|---|---|
| [`design/cgx1_architecture.json`](../design/cgx1_architecture.json) | Shared numeric design targets | Primary file for mirrored target values |
| [`mechanical/cgx1_card.scad`](../mechanical/cgx1_card.scad) | Card mechanical source | Edit this before regenerating card mesh |
| [`mechanical/cgx1_dock.scad`](../mechanical/cgx1_dock.scad) | Dock mechanical source | Edit this before regenerating dock mesh |
| [`mechanical/cgx1_blueprint.svg`](../mechanical/cgx1_blueprint.svg) | Dimensioned drawing | Maintained drawing source and README preview |
| [`mechanical/cgx1_card.stl`](../mechanical/cgx1_card.stl) | Card envelope mesh | Derived from card dimensions |
| [`mechanical/cgx1_dock.stl`](../mechanical/cgx1_dock.stl) | Dock envelope mesh | Derived from dock dimensions |
| [`source/model/`](../source/model/) | Analytical calculation source | Executable engineering source |
| [`source/isa/`](../source/isa/) | Base ISA field encoder/decoder and tests | Executable reference for the public instruction field contract |
| [`source/matrix/`](../source/matrix/) | Matrix numeric, physical architecture, register-interface, banking, staging, scoreboard, INT8 arithmetic, and INT8 path references | Executable references cover functional capture/execute/result/writeback behavior and architectural invariants; they do not establish physical timing, area, power, or measured hardware performance |
| [`source/power/`](../source/power/) | Tile power-management policy and invariant tests | Executable reference for board budgets, tile states, transitions, and hysteresis |
| [`source/firmware/`](../source/firmware/) | Power state controller | Executable reference source |
| [`source/rtl/`](../source/rtl/) | Top-level state scaffold plus matrix control/storage/scoreboard/arithmetic RTL | Limited RTL including matrix issue legality, staging, per-wave hazards, signed INT8 arithmetic, composed INT8 capture-to-writeback plumbing, and a one-wave INT8 engine shell; FP16/BF16/FP8 arithmetic, physical VGPR storage, multi-wave scheduling, and complete GPU RTL remain open |

Generated compiler output, test logs, local manifests, temporary captures, IDE files, and validation scratch files are excluded from version control.

When a derived design file is regenerated, validate it against its editable source and the machine readable design targets before merging it.

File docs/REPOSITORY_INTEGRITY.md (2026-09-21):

# Repository Integrity

[Documentation index](README.md) · [Documentation style](DOCUMENTATION_STYLE.md) · [Validation](VALIDATION.md)

The repository uses separate checks for public wording, repository integrity, shared design values, local links, build success, and executable tests.

## Public wording

`check_public_repo_hygiene.ps1` scans first party public text for:

- private development terminology;
- internal tool references that do not belong in public engineering material;
- local machine residue;
- personal host identifiers;
- a short list of promotional filler phrases.

Technical workload language is not blocked merely because it uses terms such as AI or local model inference.

## Repository integrity

`check_repository_integrity.ps1` checks:

- tracked or unignored build output, logs, caches, binaries, office files, archives, and local environment files;
- private key and common access token signatures;
- probable embedded credential assignments;
- merge conflict markers;
- Windows PowerShell parser errors;
- external GitHub Actions that are not pinned to full commit hashes;
- required ignore patterns.

## Design consistency

`check_design_consistency.ps1` uses [design/cgx1_architecture.json](../design/cgx1_architecture.json) as the primary numeric design file and verifies selected mirrors in documentation, CAD, firmware, and model source.

The check includes card dimensions, dock dimensions, selected card fan thickness, power states, FP32 arithmetic target, memory capacity, memory bandwidth, matrix-engine count, matrix numeric-policy flags, frozen matrix tile shapes, register contract, issue timing, latency, whole-wave capture/writeback interface requirements, staging capacity, modulo-8 bank-class placement, matrix-to-matrix pending-destination interlock status, capture/active staging capacity and status, output-result staging status, per-wave scoreboard status, signed INT8 arithmetic status, cycle-0 result bypass status, composed INT8 path status, single-engine INT8 shell status, and theoretical dense-rate targets.

## Negative controls

Major repository gates include an executable negative control. Each test creates a scoped invalid input, requires the validator to reject it, verifies the expected finding, and removes the temporary input in a `finally` block.

Build and validation output remains under ignored `build/` and `out/` paths. The Windows repository workflow and path-scoped Ubuntu RTL workflow do not publish build artifacts. External actions remain pinned to full commit hashes. The checks do not reset, clean, rewrite history, or delete unrelated repository state.

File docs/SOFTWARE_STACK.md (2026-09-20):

# Software Stack

[Documentation index](README.md) · [Engineering specification](ENGINEERING_SPEC.md) · [Project status](STATUS.md) · [Validation](VALIDATION.md)

A usable GPU requires more than silicon. CGX 1 includes a software implementation plan so firmware, drivers, compilers, media support, diagnostics, and conformance can be developed alongside hardware.

Software-visible hardware behavior is defined by [ISA and Execution Model](ISA.md), [Matrix Engine Architecture](MATRIX_ENGINE.md), [Virtual Memory](VIRTUAL_MEMORY.md), and [Scheduling and Preemption](SCHEDULING_PREEMPTION.md). Driver and compiler work must not invent incompatible behavior outside those contracts.

## Firmware

Initial firmware responsibilities:

- board identity and revision;
- reset and clock sequencing;
- PCIe negotiation;
- external dock detection;
- power state control;
- thermal and flow monitoring;
- fault logging;
- firmware update and recovery;
- diagnostic mailbox exposed to the host.

## Linux path

The initial Linux driver path should establish:

1. PCIe enumeration;
2. BAR/resource mapping;
3. interrupt handling;
4. memory allocation and mapping;
5. device reset and recovery;
6. firmware mailbox and telemetry;
7. basic display initialization;
8. Vulkan compute;
9. basic Vulkan graphics;
10. shader compiler expansion and conformance;
11. media integration;
12. ray tracing and advanced graphics.

The architecture does not require Resizable BAR for basic operation. A bounded aperture and command/memory paging path remains part of the host compatibility target.

## Windows path

The Windows path follows stable firmware and basic Linux hardware bring up.

Target work includes:

- WDDM device management;
- memory manager integration;
- reset/recovery behavior;
- display miniport work;
- Direct3D 12 user mode driver;
- Vulkan user mode support;
- media encode/decode interfaces;
- shader compiler integration;
- diagnostics and crash collection.

## Graphics and compute APIs

Initial targets:

- Vulkan;
- Direct3D 12;
- OpenCL or another open compute interface where practical;
- platform media APIs for AV1, HEVC, and H.264;
- development diagnostics and profiling interfaces.

CUDA compatibility is not claimed.

## Command and queue ABI

The driver/runtime queue ABI maps logical queues onto the 64 resident hardware queue contexts described in [Scheduling and Preemption](SCHEDULING_PREEMPTION.md). Queue state carries process/address-space identity, priority, engine class, fault state and command-ring position.

The exact binary command-packet format remains to be frozen with the first command-processor reference model.

## Compiler work

The compiler targets the native wave32 ISA in [ISA and Execution Model](ISA.md) and must eventually cover:

- shader front ends and intermediate representation;
- instruction selection for the CGX execution model;
- register allocation;
- scheduling;
- memory operations and synchronization;
- wave/workgroup lowering;
- graphics stage lowering;
- ray tracing operations;
- matrix operations;
- debug information;
- reproducible conformance failures.

Matrix lowering must consume advertised component types, scope, dimensions or granularities, layouts, and modifiers from the device capability contract. Software must not assume one universal physical matrix tile shape.

## Media path

The architecture target includes four encode and four decode engines. Software work must expose only functions implemented by the finished media hardware and verified against the relevant codec and platform requirements.

## Local model workloads

CGX 1 is intended to support local model inference and development workloads through its large memory capacity and general compute path. The architecture now defines theoretical dense matrix arithmetic targets, but it still does not publish an independent AI TOPS benchmark figure. No inference speed claim is made without implemented matrix hardware, compiler support, and measured software results.

## Conformance and compatibility

A shipping implementation requires:

- Vulkan conformance;
- Direct3D/WDDM qualification appropriate to the final Windows driver;
- display link compliance;
- media codec validation;
- reset and recovery testing;
- game and application compatibility;
- long duration workload testing.

See [Validation](VALIDATION.md) for the evidence expected at each hardware stage.

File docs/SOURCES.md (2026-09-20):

# Public Sources

[Documentation index](README.md) · [Reference comparison](REFERENCE_COMPARISON.md) · [Prototype procurement](PROTOTYPE_PROCUREMENT.md)

Accessed September 20, 2026 unless otherwise noted.

## GPU and memory references

1. **NVIDIA RTX PRO 6000 Blackwell Workstation Edition product datasheet.** Product figure: 125 TFLOPS FP32, 380 RT TFLOPS, 96 GB GDDR7 ECC, 1.792 TB/s memory bandwidth, four NVENC, four NVDEC, 600 W, 5.4 inch × 12 inch dual slot.  
   https://www.nvidia.com/content/dam/en-zz/Solutions/data-center/rtx-pro-6000-blackwell-workstation-edition/workstation-blackwell-rtx-pro-6000-workstation-edition-nvid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

2. **NVIDIA RTX PRO 6000 Blackwell product family.** Current product family and form factor reference.  
   https://www.nvidia.com/en-us/products/workstations/professional-desktop-gpus/rtx-pro-6000-family/

3. **NVIDIA RTX Blackwell PRO GPU Architecture.** Architecture appendix lists 126.0 TFLOPS FP32 and 381.8 RT TFLOPS for the RTX PRO 6000 Blackwell Workstation Edition. This differs slightly from the product datasheet; [Reference Comparison](REFERENCE_COMPARISON.md) uses the product datasheet values.  
   https://www.nvidia.com/content/dam/en-zz/Solutions/design-visualization/quadro-product-literature/pdf/NVIDIA-RTX-Blackwell-PRO-GPU-Architecture-v1_1.pdf

4. **NVIDIA GeForce RTX 5090 product specifications.** 21,760 CUDA cores, 32 GB GDDR7, 575 W total graphics power.  
   https://www.nvidia.com/en-us/geforce/graphics-cards/50-series/rtx-5090/

5. **NVIDIA RTX Blackwell GPU Architecture.** Architecture appendix publishes approximately 104.8 TFLOPS peak FP32 for RTX 5090.  
   https://images.nvidia.com/aem-dam/Solutions/geforce/blackwell/nvidia-rtx-blackwell-gpu-architecture.pdf

6. **Samsung HBM4 commercial shipment information.** Up to 3.3 TB/s per stack, 24 to 36 GB using 12 layers, and up to 48 GB with 16 layer stacking.  
   https://news.samsungsemiconductor.com/global/samsung-ships-industry-first-commercial-hbm4-with-ultimate-performance-for-ai-computing/

7. **Samsung HBM product information.**  
   https://semiconductor.samsung.com/dram/hbm/

8. **SK hynix HBM4 technology demonstrations.** Includes 48 GB 16 layer development references.  
   https://news.skhynix.com/en/sk-hynix-showcases-next-generation-ai-memory-innovations-at-ces-2026/

9. **Micron HBM4 product information.**  
   https://www.micron.com/products/memory/hbm/hbm4

## Process and PCIe references

10. **TSMC 2026 annual meeting material.** N2 entered high volume manufacturing in Q4 2025; N2P and A16 volume production are scheduled for the second half of 2026.  
    https://investor.tsmc.com/sites/ir/shareholders-meeting/2026-06-04/2026AGM_Agenda_wmn.pdf

11. **TSMC A16.** TSMC states A16 is production ready in 2H26 and targets HPC with backside power delivery.  
    https://www.tsmc.com/english/dedicatedFoundry/technology/logic/l_A16

12. **PCI SIG PCI Express 6.0.** PCI SIG states PCIe 6.0 maintains backward compatibility with previous PCIe generations.  
    https://pcisig.com/pci-express-6.0-specification

13. **PCI Express Card Electromechanical specification overview.** Current approved CEM revision information.  
    https://pcisig.com/specification-overview/pci-express-cem

## Prototype component references

14. **Corsair XR5 240 radiator.** Published dimensions: 280 × 120 × 30 mm. Price snapshot: $74.99.  
    https://www.corsair.com/us/en/p/custom-liquid-cooling/cx-9030002-ww/hydro-x-series-xr5-240mm-water-cooling-radiator-cx-9030002-ww

15. **Alphacool ES Reservoir DDCzero 1U with Pump, part 14571.** Published dimensions: 112 × 57 × 41.95 mm; up to 220 L/h maximum flow and 1.4 m head.  
    https://shop.alphacool.com/detail/index/sArticle/22592

16. **Titan Rig US listing for Alphacool 14571.** Price snapshot: $199.99.  
    https://www.titanrig.com/alphacool-es-reservoir-ddczero-1u-with-pump.html

17. **Same Sky CFM-5010B-170-361-22.** Active 12 V, 50 × 50 × 10 mm, PWM/tachometer fan reference.  
    https://www.sameskydevices.com/product/thermal-management/dc-fans/axial-fans/cfm-5010b-170-361-22

18. **Mean Well LRS-600N2-48.** 48 V, 600 W, 12.5 A external supply reference.  
    https://www.digikey.com/en/products/detail/mean-well-usa-inc/LRS-600N2-48/21531502

19. **AMD Alveo U50 data sheet.** Production U50: 75 W, 8 GB HBM2, Gen3 ×16 / Gen4 ×8, up to 316 GB/s measured peak HBM2 bandwidth with the documented qualification.  
    https://docs.amd.com/r/en-US/ds965-u50/Product-Details

20. **AMD Alveo U50 product page.** Reference procurement source.  
    https://www.amd.com/en/products/accelerators/alveo/u50/a-u50-p00g-pq-g.html

21. **JLCPCB assembly pricing reference.** Obtain a new quote from final manufacturing files before ordering.  
    https://jlcpcb.com/help/article/pcb-assembly-price

## Architecture standards references

22. **UCIe Consortium UCIe 3.0 specification overview.** UCIe 3.0 adds 48 GT/s and 64 GT/s data rates, priority sideband packets, fast throttle/emergency shutdown and expanded management features.  
    https://www.uciexpress.org/specifications

23. **Khronos Vulkan Roadmap 2026.** Defines the 2026 roadmap milestone for newer mid/high-end devices and lists features including fragment shading rate, shader clock, compute shader derivatives, cooperative matrix and presentation extensions.  
    https://github.khronos.org/Vulkan-Site/spec/latest/appendices/roadmap.html

24. **PCI-SIG Process Address Space ID (PASID).** Defines the 20-bit PASID field and process-address-space identification model.  
    https://pcisig.com/PCIExpress/ECN/Base/ProcessAddressSpaceID

25. **PCI-SIG PASID Translation.** Defines PASID use with address translation services and page request behavior.  
    https://pcisig.com/PCIExpress/ECN/Base/PASIDTranslation

26. **IEEE 754-2019, IEEE Standard for Floating-Point Arithmetic.** Base reference for binary floating-point formats, operations, exceptions, and default handling.  
    https://standards.ieee.org/ieee/754/6210/

27. **Intel Deep Learning Boost bfloat16 technical reference.** Describes BF16 as one sign bit, eight exponent bits, and seven fraction bits, with BF16 dot-product accumulation to FP32.  
    https://www.intel.com/content/www/us/en/developer/articles/technical/intel-deep-learning-boost-new-instruction-bfloat16.html

28. **Open Compute Project OCP 8-bit Floating Point Specification (OFP8), Revision 1.0.** Defines E4M3 and E5M2 encodings, special values, rounding, and saturating/non-saturating conversion behavior.  
    https://www.opencompute.org/documents/ocp-8-bit-floating-point-specification-ofp8-revision-1-0-2023-12-01-pdf-1

29. **Open Compute Project Microscaling Formats (MX) Specification, Version 1.0.** Defines block-scaled microscaling formats and shared scale semantics; ordinary OFP8 support does not by itself establish MX support.  
    https://www.opencompute.org/documents/ocp-microscaling-formats-mx-v1-0-spec-final-pdf

30. **Khronos Vulkan specification, cooperative matrices.** Cooperative matrix storage and computation are distributed across a scope such as a subgroup, while supported type and dimension combinations are enumerated by the implementation.  
    https://registry.khronos.org/vulkan/specs/latest-ratified/pdf/vkspec.pdf

31. **Clang AMDGPU builtin reference, WMMA.** Documents wave32 cooperative matrix instructions, including 16 × 16 matrix operations and FP32 accumulator fragments represented as eight float values per wave32 lane in published WMMA interfaces. Used as an external architectural precedent, not as the CGX 1 fragment contract.  
    https://clang.llvm.org/docs/AMDGPUBuiltinReference.html

32. **AMD GPUOpen, WMMA on RDNA 3.** Describes 16 × 16 × 16 wave matrix multiply-accumulate operation and wave32/wave64 cooperative execution. Used as a public implementation reference when evaluating CGX 1 tile organization.  
    https://gpuopen.com/learn/wmma_on_rdna3/

## Repository tooling reference

33. **actions/checkout v7.0.1.** Repository workflow is pinned to commit `3d3c42e5aac5ba805825da76410c181273ba90b1`.  
    https://github.com/actions/checkout/releases/tag/v7.0.1

Retail listings are sourcing references, not endorsements or guarantees of future availability.

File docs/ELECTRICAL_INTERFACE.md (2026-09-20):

# Electrical Interface

[Documentation index](README.md) · [Engineering specification](ENGINEERING_SPEC.md) · [Thermal and power](THERMAL_POWER.md) · [Power management](POWER_MANAGEMENT.md) · [Validation](VALIDATION.md)

## Power sources

CGX 1 has two input domains:

1. the normal PCIe slot supply used for boot and qualified standalone modes;
2. a rear 48 V DC input used for docked high power operation.

The external 48 V source is supplied by a separate certified AC/DC unit. The thermal dock distributes and monitors the low voltage DC path but does not contain mains conversion.

## Power states

| State | Board limit | Maximum host slot demand | Entry requirement |
|---|---:|---:|---|
| P0 Safe Boot | 25 W | 25 W | Always available after reset |
| P1 Slot Eco | 45 W | 45 W | Host qualified for the requested slot power |
| P2 Slot Max | 70 W | 70 W | Host qualified for the requested slot power |
| P3 Dock Quiet | 220 W | 25 W | External 48 V present and coolant flow valid |
| P4 Dock Full | 360 W | 25 W | External 48 V present and coolant flow valid |

P3 and P4 take the remaining board power from the external 48 V path.

## Dock loss behavior

Loss of either of the following while P3 or P4 is active is treated as a dock fault:

- external 48 V presence;
- valid coolant flow.

The reference controller returns directly to **P0 Safe Boot**, limiting the board to 25 W. It does not jump to P2 because doing so could increase PCIe slot demand at the same moment the external source disappears.

A production device may later support a higher host qualified fallback, but that behavior requires explicit host capability detection and validation. P0 remains the default fault state.

## Input isolation

The final board requires hardware isolation that prevents either input source from backfeeding the other.

Required behavior:

- slot power cannot energize the external 48 V connector;
- external 48 V cannot backfeed the motherboard slot;
- the card can boot with the external source absent;
- P3/P4 rail enable is blocked until external power and coolant flow are valid;
- hardware fault logic can reduce power without depending on normal GPU firmware execution.

## External input

At 360 W, the ideal current from a 48 V source is 7.5 A before conversion and dock overhead.

The design target is:

- 48 V nominal input;
- 10 A minimum supply capability;
- 12 A preferred for transient and dock margin;
- locking connector and contacts rated above continuous design current;
- bulk filtering in the dock;
- intermediate conversion and point of load regulation on the card.

## Monitoring

Engineering boards should measure:

- PCIe slot voltage and current;
- external 48 V voltage and current;
- major regulator rail voltage/current;
- GPU/package temperature;
- HBM temperature;
- regulator temperature;
- coolant inlet and outlet temperature;
- coolant flow;
- pump speed;
- card fan speed;
- radiator fan speed.

## Internal allocation boundary

This document defines the external and board-level electrical limits. [Power Management](POWER_MANAGEMENT.md) defines how compute-tile capacity is allocated inside those limits.

The internal power manager cannot promote the board into a higher P-state. It receives the already-permitted state from the firmware safety controller and must keep authorized non-tile plus per-tile budgets within that board limit.

## Reference implementation

The public C implementation is in [source/firmware/cgx1_power.c](../source/firmware/cgx1_power.c). The SystemVerilog top level scaffold is in [source/rtl/cgx1_top.sv](../source/rtl/cgx1_top.sv).

Both are reference boundaries, not a production power controller or complete GPU.

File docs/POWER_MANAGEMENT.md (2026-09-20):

# CGX 1 Power Management

[Documentation index](README.md) · [Engineering specification](ENGINEERING_SPEC.md) · [Electrical interface](ELECTRICAL_INTERFACE.md) · [Scheduling and preemption](SCHEDULING_PREEMPTION.md)

This document defines the internal power-management contract beneath the existing P0-P4 board power states. It is an architecture target and executable policy reference, not a characterized silicon voltage/frequency curve.

## Authority

CGX 1 separates safety authority from performance policy.

- The existing firmware safety controller selects the permitted **board power state** and retains authority over dock, coolant, thermal, and hardware-fault fallback.
- The I/O-die power-management controller allocates compute-tile capacity **inside** the power limit of that board state.
- The scheduler requests capacity and consumes a tile-eligibility mask. It does not directly control voltage rails, power gates, or isolation.
- The internal controller may reduce performance below the board-state maximum at any time. It may not raise the board into a higher P-state.

This keeps P0-P4 as electrical/safety envelopes instead of turning them into fixed tile-count presets.

## Board states and tile states

Board power limits remain unchanged:

| Board state | Board limit | Dock required | Highest tile operating class permitted |
|---|---:|---|---|
| P0 Safe Boot | 25 W | No | T2 Idle |
| P1 Slot Eco | 45 W | No | T3 Eco |
| P2 Slot Max | 70 W | No | T4 Nominal |
| P3 Dock Quiet | 220 W | Yes | T5 Boost |
| P4 Dock Full | 360 W | Yes | T5 Boost |

The tile-state cap is a permission, not a command. A P4 board may have zero, one, or several schedulable tiles depending on workload, telemetry, and the board budget.

Tile operating states:

| Tile state | Meaning | Scheduler eligible |
|---|---|---|
| T0 Off | Compute-tile power gated; architectural execution state not retained | No |
| T1 Retention | Minimum retained state for restart; execution unavailable | No |
| T2 Idle | Powered/coherent control state; execution clocks substantially gated | No |
| T3 Eco | Schedulable low-power execution class | Yes |
| T4 Nominal | Schedulable normal execution class | Yes |
| T5 Boost | Schedulable highest performance class permitted by available electrical and thermal headroom | Yes |

T3-T5 are policy classes, not frozen frequencies or voltages.

## DVFS boundary

The existing GPU-core target range is **0.55 V to 0.90 V**, with 2.65 GHz sustained and 2.80 GHz peak architecture clock targets.

CGX 1 does **not** publish a fabricated V/F curve. Exact per-tile voltage/frequency points require timing closure, process data, leakage analysis, power characterization, and silicon measurement.

The sequencing contract is still fixed:

- performance may increase only after the required voltage state is established;
- voltage may decrease only after clock frequency is at or below the lower safe target;
- a tile may not become scheduler eligible until power, clocks, isolation, and coherence state are valid;
- a tile leaving execution must become scheduler ineligible before retention or power gating.

The four compute tiles target independent DVFS control. This does not imply four independent software-visible GPUs.

## Board-budget invariant

The power controller tracks a non-tile budget plus an authorized budget for each compute tile.

For an active board state:

```text
non-tile budget
+ tile 0 budget
+ tile 1 budget
+ tile 2 budget
+ tile 3 budget
<= active P-state board limit
```

The reference model rejects negative, non-finite, and over-limit requests.

These are controller budgets, not claims that an uncharacterized tile consumes a specific number of watts. Final budgets must be calibrated against rail telemetry and characterized silicon.

There is intentionally **no fixed mapping such as P1 = one tile or P2 = two tiles**. The controller may prefer more tiles at lower V/F or fewer tiles at higher V/F when measurements demonstrate that one policy is more efficient.

## Clock and power gating

The physical implementation should support clock gating below the tile level for idle execution resources, including:

- CU groups;
- texture blocks;
- raster/back-end blocks;
- matrix engines;
- ray engines;
- tile-local fabric and cache interfaces where coherence permits.

Whole-tile power gating is separate from fine-grained clock gating.

A unit being clock gated must not make its parent tile disappear from coherence or scheduling state unless the corresponding tile transition is completed.

## Memory and package-cache domains

HBM and package-cache power policy is independent of active compute-tile count.

A tile becoming idle or off must not automatically power down memory required by:

- another compute tile;
- PCIe transfers;
- display scanout;
- media engines;
- firmware;
- page tables or fault handling.

P0 guarantees the control and diagnostic behavior required for safe boot. CGX 1 does **not** currently claim that all HBM capacity remains fully active and addressable inside the 25 W P0 envelope. That behavior must be established by memory-controller design and measured power data.

## Orderly tile power-down

A normal transition toward retention/off follows this logical order:

1. stop new dispatch to the tile;
2. drain or preempt current work at an allowed boundary;
3. resolve dirty coherent state by writeback or ownership transfer;
4. remove the tile from the scheduler-eligible mask;
5. reduce clock state in a safe V/F order;
6. gate execution clocks;
7. assert isolation before retention/off;
8. enter retention or remove tile power.

A dirty coherent tile must not be intentionally power gated through the orderly path before its required state is resolved.

## Orderly tile power-up

A normal wake follows this logical order:

1. establish tile power;
2. establish the required voltage state;
3. verify power-good;
4. start and stabilize required clocks;
5. restore or initialize retained state;
6. release isolation;
7. join the coherence domain;
8. publish scheduler eligibility only after the tile is ready to execute.

The final hardware design must define timing and acknowledgement signals for each boundary.

## Emergency behavior

Emergency safety has higher authority than orderly performance transitions.

Hardware fault, emergency thermal protection, or dock/coolant loss while a docked state is active may require immediate isolation before normal drain/writeback can finish. In that case:

- the tile is removed from scheduler eligibility immediately;
- unfinished work may be lost;
- dirty state that could not be made coherent is not claimed to be preserved;
- firmware/driver recovery must report the resulting context or device loss;
- the existing board-level controller retains the P0 fallback behavior.

The repository therefore does not claim that an emergency power cut is equivalent to an orderly tile shutdown.

## Hysteresis

Performance promotion and demotion require hysteresis so brief utilization changes do not cause continuous voltage, frequency, or power-gate oscillation.

The architecture requires hysteresis but does not freeze time constants or sample counts. Those values must come from controller-loop stability work and silicon characterization.

Emergency fault response is not delayed by performance hysteresis.

## Scheduler contract

The power manager publishes an eligible-tile mask.

The scheduler:

- dispatches only to eligible tiles;
- stops assigning new work before an orderly tile shutdown;
- cooperates with preemption/drain requests;
- redistributes runnable work when available tile count changes;
- retains its fairness/aging guarantees across eligible resources.

Power management must not create a permanently starved queue simply because tile availability changes.

## Reference implementation

[`source/power/cgx1_power_management.hpp`](../source/power/cgx1_power_management.hpp) and its executable tests model:

- unchanged P0-P4 board limits;
- rejection of invalid board-state and tile-state values;
- dock-state identification;
- maximum tile classes per board state;
- scheduler eligibility;
- combined rejection of plans that violate either tile-state caps or the active board budget;
- total board-budget enforcement;
- exhaustive rejection of skipped orderly tile transitions;
- V/F sequencing guards;
- coherence-ready guards before wake reaches Idle or becomes scheduler eligible;
- dirty-state and scheduler-drain guards;
- emergency isolation conditions;
- configurable hysteresis acceptance.

The reference implementation is a policy/invariant model. It is not a regulator driver, physical power controller, or measured silicon power model.

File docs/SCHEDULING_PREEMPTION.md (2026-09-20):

# Scheduling and Preemption

[Documentation index](README.md) · [ISA and execution model](ISA.md) · [Virtual memory](VIRTUAL_MEMORY.md) · [Chiplet fabric](CHIPLET_FABRIC.md) · [Power management](POWER_MANAGEMENT.md)

## Queue architecture

The central I/O die owns the global queue manager. Each compute tile has a local dispatch scheduler.

The first architecture target provides **64 resident hardware queue contexts** across graphics/compute execution and **8 priority levels**. Operating-system/runtime software may expose more logical queues by virtualizing them over resident contexts.

Queue identity includes its process/address-space identity, priority, engine class and fault state.

## Scheduling policy

The default policy is weighted fair scheduling with aging.

Priorities may favor latency-sensitive graphics, display-supporting work or system tasks, but a continuously runnable lower-priority queue must eventually receive service.

Work placement is power-aware. The global scheduler knows which tiles are powered and eligible in P0-P4 states and must not dispatch work to a gated tile.

## Preemption boundaries

Mandatory baseline boundaries are deliberately implementable:

- compute: workgroup boundary;
- graphics: draw/dispatch packet boundary;
- queue: command-packet boundary.

Finer wave-level preemption is a future target after register/state-save bandwidth and latency are characterized. It is not required by the first hardware implementation.

A page fault may stall/replay the affected work without waiting for the entire queue to complete.

## Context state

A preemptible context includes:

- queue read/write state;
- program/dispatch state;
- register and execution masks needed by the chosen preemption boundary;
- memory/translation identity;
- barrier and synchronization state that must survive the boundary;
- fault and watchdog state.

The implementation may keep context state on chip or spill it to protected memory.

## Watchdog and recovery

A stuck workload escalates through the smallest reset domain that can restore forward progress:

1. engine reset;
2. compute-tile reset;
3. full-device reset.

Firmware records the failing queue/context and reset level.

A graphics or compute hang should not immediately discard unrelated work if an engine- or tile-level recovery succeeds.

## Power-state behavior

P0-P4 define board power envelopes, not fixed active-tile counts. The power-management controller publishes an eligible-tile mask, and the scheduler must not dispatch to a tile outside that mask.

For an orderly reduction in available capacity, the scheduler stops new dispatch and drains or preempts work at an allowed boundary before the tile can enter retention/off. Dirty coherent state must be resolved before orderly power gating.

Emergency thermal/dock faults retain authority to drop immediately to the safe P0 behavior defined by the board safety controller. Emergency isolation may discard unfinished work when an orderly drain cannot complete.

See [Power Management](POWER_MANAGEMENT.md).

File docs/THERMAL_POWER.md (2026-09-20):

# Thermal and Power Design

[Documentation index](README.md) · [Mechanical design](MECHANICAL_DESIGN.md) · [Electrical interface](ELECTRICAL_INTERFACE.md) · [Power management](POWER_MANAGEMENT.md) · [Prototype build](PROTOTYPE_BUILD.md)

## Full power budget

| Subsystem | Target power | Budget role |
|---|---:|---|
| Four compute tiles | 230 W | Main execution load |
| I/O, display, media, and fabric | 25 W | Central logic and interfaces |
| HBM4 | 50 W | Two memory stacks |
| Package level SRAM/cache | 12 W | Stacked/package cache target |
| VRM and conversion loss | 28 W | Conversion loss allowance |
| Fans, sensors, and board overhead | 15 W | Card and dock support loads |
| **Total** | **360 W** | **P4 sustained board target** |

The 450 W value is an electrical transient design ceiling, not a sustained thermal target.

The 230 W compute-tile line is a P4 architecture budget for all four tiles together, not a fixed per-tile allocation. [Power Management](POWER_MANAGEMENT.md) permits the internal controller to distribute authorized tile budget dynamically while keeping the total board request inside the active P-state limit.

## 48 V input

At 360 W, an ideal 48 V source supplies 7.5 A before conversion and dock overhead.

The design calls for:

- certified external 48 V AC/DC supply;
- 10 A minimum capability;
- 12 A preferred for transient and dock margin;
- no mains conversion inside the coolant dock.

Docked P3/P4 operation limits host slot draw to 25 W. The external path supplies the remaining board power.

## Coolant calculation

The analytical model uses water like coolant properties:

```text
mass flow = 1.5 L/min × 0.997 kg/L / 60
          ≈ 0.0249 kg/s

coolant rise = 360 W / (mass flow × 4186 J/kg K)
             ≈ 3.45 °C
```

Thermal resistance targets:

- junction to coolant: ≤ 0.085 °C/W;
- radiator coolant to ambient effective: ≤ 0.040 °C/W at the full fan curve.

Using a 35 °C ambient analysis point, 360 W load, 1.5 L/min coolant flow, and half the modeled block coolant rise in the junction estimate gives approximately **81.7 °C**.

This is an analytical target. P0 hardware must establish measured temperatures and flow.

## Prototype cooling hardware

| Component | Reference | Published dimension/capability used by the design |
|---|---|---|
| Radiator | Corsair XR5 240 | 280 × 120 × 30 mm |
| Radiator fans | Two 120 mm pressure oriented fans | 25 mm thickness class assumed in dock packing |
| Pump/reservoir | Alphacool ES Reservoir DDCzero 1U, part 14571 | 112 × 57 × 41.95 mm, up to 220 L/h published maximum |
| Card fans | Same Sky CFM-5010B-170-361-22 | 50 × 50 × 10 mm, PWM/tachometer |
| Dock envelope | CGX 1 target | 310 × 210 × 75 mm |

Published pump maximum flow is not the same as loop flow under restriction. P0 must measure actual loop flow and demonstrate the 1.5 L/min operating target or revise the thermal design.

## Failure behavior

Independent hardware protection is required for:

- loss of coolant flow in P3/P4;
- loss of external 48 V in P3/P4;
- external input over voltage;
- package over temperature;
- HBM temperature beyond the selected vendor limit;
- VRM over temperature;
- major rail over current.

The reference controller returns to P0 at 25 W on dock loss, invalid coolant flow, hardware fault, GPU temperature at or above 88 °C, or VRM temperature at or above 105 °C.

Final production thresholds must come from characterized component limits rather than these prototype reference values.

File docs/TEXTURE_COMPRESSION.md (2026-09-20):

# Texture and Lossless Surface Compression

[Documentation index](README.md) · [Graphics pipeline](GRAPHICS_PIPELINE.md) · [Engineering specification](ENGINEERING_SPEC.md)

## Texture subsystem

CGX 1 targets **25 texture blocks per compute tile**, or **100 blocks total**. One block is shared by two compute units.

Each texture block targets four bilinear sample results per cycle under a simple cache-resident case. At the 2.80 GHz peak clock, the arithmetic ceiling is:

```text
100 blocks x 4 bilinear samples/cycle x 2.80 GHz
= 1,120 Gsamples/s
```

That number is a sampler arithmetic target. It is not a guaranteed texture rate and does not predict frame rate.

## Filtering

Target filtering modes:

- point;
- bilinear;
- trilinear;
- anisotropic filtering through 16x;
- gather;
- explicit LOD and gradients;
- normalized and unnormalized coordinates where the API requires them.

Format decode targets include BC1-BC7, ETC2/EAC and ASTC LDR. Final API conformance determines the complete required format table.

Each texture block uses a read-only sampler cache backed by the tile L2. Sampler-cache capacity and associativity are physical-design parameters and are not frozen yet; the tile-L2 target is 16 MB per compute tile.

## Lossless surface compression

CGX uses a lossless surface-compression layer between tile L2 and the package cache/HBM path.

Compression is defined in **256-byte surface blocks**. Color blocks may be stored as:

- raw/uncompressed;
- constant-color;
- lossless delta-coded data.

Depth/stencil surfaces have a separate lossless representation suited to hierarchical Z/stencil state.

Fast clears may be represented as metadata without immediately writing every pixel value.

## Correctness rules

Compression must be invisible to shaders, host software and display/media consumers.

There is **no guaranteed compression ratio**. A block that cannot be represented profitably or safely is stored raw.

Operations whose atomicity or byte-addressability is incompatible with a compressed representation force the affected block to a correctness-preserving raw state before the operation completes.

Compression metadata participates in cache coherence. A consumer may not observe stale metadata paired with newer surface data or the reverse.

## Why compression is part of the architecture

HBM4 bandwidth is large but not free. Avoiding unnecessary HBM transfers reduces energy, package-fabric pressure and contention between graphics, compute, media and display traffic.

The purpose of compression is therefore bandwidth and power efficiency, not a headline multiplier.

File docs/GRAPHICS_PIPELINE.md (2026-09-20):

# CGX 1 Graphics Pipeline

[Documentation index](README.md) · [ISA and execution model](ISA.md) · [Texture and compression](TEXTURE_COMPRESSION.md) · [Chiplet fabric](CHIPLET_FABRIC.md)

CGX 1 presents **one logical GPU**. The four compute tiles are not exposed as AFR or four independent adapters.

## Work flow

```text
command queues
    |
global command/queue manager
    |
task / mesh / legacy geometry work on compute units
    |
primitive setup and screen-space binning
    |
dynamic 32 x 32 pixel macro-tile ownership
    |
tile-local rasterization
    |
fragment shading / texture
    |
depth-stencil / color back end
    |
lossless surface compression
    |
tile L2 -> package cache -> HBM4
```

Legacy vertex, tessellation, and geometry stages lower into the same programmable execution model used by mesh/task paths. Mesh/task shading is a first-class target.

## Tile organization

Each of four compute tiles contains:

- 50 compute units;
- 25 texture blocks;
- 4 raster partitions;
- 64 aggregate color/depth result lanes;
- a 16 MB tile L2 slice.

Device totals are therefore:

- 200 compute units;
- 100 texture blocks;
- 16 raster partitions;
- 256 color/depth result lanes;
- 64 MB aggregate tile L2.

A result lane is an architectural back-end lane, not a frame-rate claim. Actual rate depends on format, blending, depth/stencil state, compression, samples, cache behavior and memory traffic.

## Screen-space ownership

Raster work is divided into **32 x 32 pixel macro-tiles**. A macro-tile is owned by one compute tile while its color/depth updates are active. Ownership may be assigned dynamically to balance load.

Primitives that overlap more than one macro-tile are binned to each required owner. Final color/depth blending for an owned macro-tile remains local to the owning tile until the result is written through L2.

This avoids treating the device as four separately rendered frame regions and reduces cross-tile read/modify/write traffic for render targets.

## Raster and depth path

The raster target includes:

- triangle and line setup;
- hierarchical Z/stencil rejection;
- early and late depth/stencil operation;
- sample coverage and centroid/sample interpolation;
- 1x, 2x, 4x and 8x MSAA targets;
- programmable fragment shading-rate state;
- ordered color blending within a render target ownership region.

Raster partitions may feed any local compute-unit group through the tile scheduler. The final physical partition-to-CU wiring remains a layout decision.

## Cross-tile resources

Read-mostly resources may be cached by multiple tiles. Writable resources use the package coherence directory and normal memory ordering rules.

Render-target ownership is a performance policy, not an isolation boundary. Storage images, atomics, queues and general compute data remain globally addressable.

## Presentation

Display engines remain on the central I/O die. Completed scanout surfaces become visible to display only after required device-scope ordering is complete.

The graphics pipeline is designed so display timing does not depend on one specific compute tile remaining active.

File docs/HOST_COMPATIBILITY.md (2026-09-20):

# Host Compatibility

[Documentation index](README.md) · [Mechanical design](MECHANICAL_DESIGN.md) · [Electrical interface](ELECTRICAL_INTERFACE.md)

CGX 1 is described by host classes rather than personal computer models.

## Low profile OEM desktop class

Typical constraints:

- low profile expansion slot;
- one adjacent slot available for a dual slot card;
- limited internal PSU capacity;
- older PCIe generation or firmware;
- limited chassis airflow.

CGX 1 addresses these constraints with a 167.5 × 68.5 mm PCB target, interchangeable low profile bracket, a 25 W Safe Boot state, qualified slot modes, and an external high power path.

Docked P3/P4 operation caps host slot demand at 25 W. A dock fault returns the reference controller to P0 at 25 W rather than switching to the 70 W slot state.

Resizable BAR is not assumed. The architecture includes a bounded aperture path and large local memory/cache hierarchy.

## Compact and conventional tower class

Typical constraints:

- greater bracket flexibility;
- more internal volume but uncertain PSU headroom;
- wider PCIe generation range;
- stronger airflow than a slim OEM chassis.

The same PCB can use low profile or full height bracket metalwork. The external 48 V path remains the preferred full power source because it avoids relying on spare host PSU capacity.

## PCIe negotiation

The native controller target is PCIe Gen 6 ×16 with backward interoperability through earlier PCIe generations. A lower negotiated link does not change local VRAM capacity or card power capability, but host transfer limited workloads can lose performance.

## Required fit checks

Before installation in a specific chassis, verify:

1. card length clearance of at least 167.5 mm plus rear bracket service clearance;
2. low profile or full height bracket compatibility;
3. two slot width clearance for 39.5 mm installed thickness;
4. rear access for coolant and 48 V services;
5. no obstruction of motherboard or chassis connectors;
6. PCIe ×16 mechanical slot availability;
7. host firmware behavior with an add in display/compute device;
8. placement for the 310 × 210 × 75 mm thermal dock;
9. hose routing from the rear bracket to the dock;
10. placement for the separate certified 48 V AC/DC supply.

A chassis family name alone is not proof of physical fit because internal layouts can change between revisions.

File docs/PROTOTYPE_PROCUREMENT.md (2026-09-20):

# Prototype Procurement Guide

[Documentation index](README.md) · [Prototype build](PROTOTYPE_BUILD.md) · [Mechanical design](MECHANICAL_DESIGN.md) · [Unit cost](PROTOTYPE_UNIT_COST.md)

This purchasing plan supports the P0 electrothermal card and thermal dock first. P1 adds a shared HBM programmable accelerator only when PCIe, memory traffic, RTL, or host software work needs it.

Prices are snapshots checked September 20, 2026. Retail pricing and stock can change.

## Consumable manufacturing supplies

| Consumable | Suggested quantity | Snapshot price | Purpose | Source |
|---|---:|---:|---|---|
| Chip Quik SMD291SNL SAC305 lead free solder paste, 15 g | 1 | $15.95 | SMT assembly and rework | [DigiKey](https://www.digikey.com/en/products/detail/chip-quik-inc/SMD291SNL/1160001) |
| Chip Quik SMD291NL no clean flux | 1 | $11.95 | Rework and connector soldering | [DigiKey](https://www.digikey.com/en/products/detail/chip-quik-inc/SMD291NL/1160000) |
| Kester 44 63/37 solder wire, 1 oz | 1 | $15.93 | Hand assembly | [Metrocom](https://metrocomusa.com/products/b00avlm4so) |
| MG Chemicals SuperWick, 5 ft | 1 | $6.73 | Desoldering and correction | [DigiKey](https://www.digikey.com/en/products/filter/desoldering-braid-wick-pumps/265) |
| Max Pro 99.9% IPA electronics cleaner | 1 | $12.99 | Board cleanup | [Micro Center](https://www.microcenter.com/product/623506/max-pro-isopropyl-alcohol-all-purpose-cleaner-12-oz) |
| Tapes Master polyimide tape, 1 in × 36 yd | 1 | $9.75 | Thermal masking and insulation | [Walmart](https://www.walmart.com/ip/Tapes-Master-1-Mil-1-inch-x-36-Yds-Kapton-Tape-Amber-Polyimide-High-Temperature-Tape/1150397847) |
| Arctic MX-6, 4 g | 1 | $11.99 | Heater/package to cold plate interface | [Micro Center](https://www.microcenter.com/product/685652/arctic-mx-6-thermal-paste-4-g) |
| GELID GP Extreme 0.5 mm pad | 1 | $9.99 | Thin thermal gap interface | [Walmart](https://www.walmart.com/ip/Gelid-Solutions-GP-Extreme-0-5mm-Thermal-Pad-TP-GP01-A/756327260) |
| GELID GP Extreme 1.0 mm pad | 1 pack | $14.99 | Regulator/package height adjustment | [Walmart](https://www.walmart.com/ip/Gelid-Solutions-GP-Extreme-12W-Thermal-Pad-80x40x1-0-2pcs-Excellent-Heat-Conduction-Ideal-Gap-Filler-Easy-Installation/815284725) |
| GELID GP Extreme 1.5 mm pad | 1 | $14.99 | Larger thermal gaps | [Newegg](https://www.newegg.com/gelid-solutions/p/2MB-004H-00034) |
| Corsair XL8 clear coolant, 1 L | 1 | $24.99 | External cooling loop | [Corsair](https://www.corsair.com/us/en/p/custom-liquid-cooling/cx-9060007-ww/hydro-x-series-xl8-performance-coolant-1l-aca-a-clear-cx-9060007-ww) |
| EK Loop ZMT 10/16 mm tubing, 3 m | 1 | $29.99 | Dock coolant lines | [EKWB](https://www.ekwb.com/shop/accessories/tubing/10-16mm-3-8-5-8-tubing) |
| 10 AWG silicone power wire | 5 ft red + 5 ft black | $13.99 | 48 V low voltage harness | [Walmart](https://www.walmart.com/ip/326626641) |
| 18 AWG silicone wire assortment | 1 | ~$16.40 | Fans, sensors, and control wiring | [TinyRacer](https://tinyracer.com/products/18awg-silicone-electrical-wire-cable-6-colors-5ft-each-18-gauge-hookup-wires-kit-stranded-tinned-copper-wire-flexible-and-soft-super-l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) |
| Heat shrink assortment | 1 | $6.47 | Harness construction | [Walmart](https://www.walmart.com/ip/Hyper-Tough-120-Piece-Assortment-Heat-Shrink-Tubing/13708908712) |
| Black PETG filament, 1 kg | 1 spool | $14.99 | Prototype shroud, ducting, and dock shell | [Overture](https://overture3d.com/products/overture-high-speed-petg) |
| M3 stainless fastener assortment | 1 | $15.54 | Card and dock assembly | [Home Depot](https://www.homedepot.com/p/MYWISH-550-Piece-M3-x-Assorted-304-Stainless-Steel-Hex-Drive-Button-Head-Socket-Head-Cap-Screws-Assortment-Kit-SF-TZ00002/337625654) |

## P0 card and dock hardware

| Product | Quantity | Snapshot price | Use | Source |
|---|---:|---:|---|---|
| Mean Well LRS-600N2-48 | 1 | $64.00 | Separate 48 V, 600 W, 12.5 A AC/DC supply | [DigiKey](https://www.digikey.com/en/products/detail/mean-well-usa-inc/LRS-600N2-48/21531502) |
| Corsair XR5 240 radiator | 1 | $74.99 | 280 × 120 × 30 mm external heat exchanger | [Corsair](https://www.corsair.com/us/en/p/custom-liquid-cooling/cx-9030002-ww/hydro-x-series-xr5-240mm-water-cooling-radiator-cx-9030002-ww) |
| Alphacool ES Reservoir DDCzero 1U with Pump, 14571 | 1 | $199.99 | 112 × 57 × 41.95 mm compact pump/reservoir | [Titan Rig](https://www.titanrig.com/alphacool-es-reservoir-ddczero-1u-with-pump.html) |
| Noctua NF-A12x25 PWM | 2 | $38.79 each | 120 mm radiator airflow | [Newegg](https://www.newegg.com/noctua-nf-a12x25-pwm-case-fan/p/1YF-000T-000K7) |
| Same Sky CFM-5010B-170-361-22 | 2 | Check lead time/quote | 50 × 50 × 10 mm card fan, PWM + tach | [DigiKey](https://www.digikey.com/en/products/detail/same-sky-formerly-cui-devices/CFM-5010B-170-361-22/22259116) |
| Koolance QD3 coolant pairs | 2 pairs | ~$72.40 total | Dry break supply and return | [Koolance](https://koolance.com/quick-disconnect-couplings-3rd-generation-qd3) |
| EK Torque STC 10/16 fittings, 6 pack | 1 | $49.99 | Tube termination | [EKWB](https://www.ekwb.com/shop/quantum/torque-fittings/torque-stc-fittings) |
| Universal copper water block | 1 | $54.99 | First cold plate substitute | [Newegg](https://www.newegg.com/p/3C6-06GK-00XB3) |
| 48 V cartridge heaters | 4 | $27 each | Artificial GPU/package heat load | [HartSmart](https://hartsmartproducts.com/products/high-wattage-cartridge-heaters-24v-48v) |
| Anderson SB50 connector with contacts | 2 | ~$6.60 each | Removable 48 V low voltage connection | [AndyMark](https://andymark.com/products/sb50-anderson-powerpole-connector-with-contacts) |

The Mean Well unit is a separate external supply. It is not packed inside the 310 × 210 × 75 mm thermal dock.

The Same Sky fan is an active exact dimensional reference but may require lead time. A prototype can use an electrically compatible 50 × 50 × 10 mm fan as a temporary mechanical substitute, provided the actual dimensions and control features are recorded.

## P1 programmable accelerator and bench hardware

| Product | Stage | Snapshot price | Use | Source |
|---|---|---:|---|---|
| AMD Alveo U50 | P1 | $2,965.00 | Shared HBM/PCIe programmable accelerator | [AMD](https://www.amd.com/en/products/accelerators/alveo/u50/a-u50-p00g-pq-g.html) |
| Lian Li PCIe 5.0 ×16 riser | Bench | $64.99 | Operate a test card outside the chassis | [Micro Center](https://www.microcenter.com/product/694523/lian-li-pcie-50-x16-riser-cable) |
| Hakko FX-888DX | Bench | $121.47 | Soldering station | [Hakko](https://hakkousa.com/fx-888dx.html) |
| Quick 861DW | Bench | $293.78 | Hot air rework | [Elektor](https://www.elektor.com/products/quick-861dw-hot-air-rework-station-1000-w) |
| Miniware MHP30 | Bench | $99.95 | PCB preheat/local reflow | [Adafruit](https://www.adafruit.com/minihotplate) |
| AmScope SE400-Z | Bench | $291.99 | PCB inspection | [AmScope](https://amscope.com/products/se400-z) |
| PCB holder | Bench | $23.99 | Board fixture | [Walmart](https://www.walmart.com/ip/MMOBIEL-Adjustable-PCB-Holder-Circuit-Board-Holder-Tool-for-Circuit-Board-Soldering-Desoldering-Repair-Tool-360-Degree-Rotation/2203904857) |
| Rigol DHO804 | Bench | $413.10 | Four channel oscilloscope | [Rigol](https://www.rigolna.com/products/rigol-digital-oscilloscopes/dho800/) |
| Fluke 87V | Bench | $461.90 | Electrical measurements | [Home Depot](https://www.homedepot.com/b/Electrical-Electrical-Tools-Electrical-Testers-Multimeter/FLUKE/N-5yc1vZchjcZyuk) |
| FLIR C5 | Bench | $699.00 | Thermal imaging | [FLIR](https://www.flir.com/products/c5/) |

## Lower cost bench substitutes

| Standard item | Substitute | Snapshot price | Tradeoff | Source |
|---|---|---:|---|---|
| Quick 861DW | Yihua 8786D-I combined station | $59.99 | Lower airflow and thermal capacity | [Micro Center](https://www.microcenter.com/product/709629/-yihua-8786d-i-hot-air-rework-station-with-soldering-iron) |
| Hakko FX-888DX | Pinecil V2 | ~$53.14 | Portable form instead of a full bench station | [DREMC](https://store.dremc.com.au/products/pinecil-smart-mini-portable-soldering-iron-version-2) |
| Stereo microscope | 1600× USB microscope | $29.99 | No optical stereo depth perception | [Walmart](https://www.walmart.com/ip/1600X-USB-Digital-Microscope-8-LED-Lights-Stand-Portable-Handheld-Inspection-Magnifier-Compatible-Android-Windows-XP-Win-7-10-Vista-Linux-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) |
| Rigol DHO804 | FNIRSI 2C53P | $128.99 | Fewer channels and less bench capability | [Micro Center](https://www.microcenter.com/product/701500/fnirsi-2c53p-handheld-tablet-oscilloscope-multimeter-dds-signal-generator-3-in-1) |
| Fluke 87V | Klein MM420 | $69.97 | Fewer industrial meter features | [Home Depot](https://www.homedepot.com/p/Klein-Tools-600-Volt-Digital-Multimeter-TRMS-Auto-Ranging-Temp-MM420/320822810) |
| FLIR C5 | Klein IR5 spot thermometer | $69.99 | No thermal image | [Home Depot](https://www.homedepot.com/p/207004900) |
| Programmable electronic load | Four 100 W, 24 ohm aluminum resistors | ~$22.98 for four | Manual load arrangement | [Walmart](https://www.walmart.com/ip/Aluminum-Case-Resistor-100W-24Ohm-Wirewound-Yellow-2pcs/103362154) |
| Custom machined cold plate | Universal copper water block | $54.99 | Does not reproduce final internal geometry | [Newegg](https://www.newegg.com/p/3C6-06GK-00XB3) |
| AMD Alveo U50 during P0 | Omit the FPGA accelerator | $0 | P0 remains mechanical, electrical, firmware, and thermal only | — |
| AMD Alveo U50 for smaller RTL experiments | Digilent Genesys 2 class board | roughly $1,099 | No HBM and weaker representation of the intended memory system | [Digilent](https://digilent.com/reference/programmable-logic/genesys-2/start) |

## PCB fabrication

The control and power PCB should be professionally fabricated and assembled. The final quote depends on the manufacturing files, copper weight, layer count, controlled impedance requirements, via structure, surface finish, assembly side count, and component sourcing.

A public assembly pricing reference is maintained in [Sources](SOURCES.md). Obtain a fresh quote from the actual manufacturing files before ordering.

## P0 purchase order

1. separate certified 48 V AC/DC supply;
2. radiator, radiator fans, pump/reservoir, coolant, tubing, fittings, and disconnects;
3. card fans or exact dimensional surrogates;
4. cold plate substitute and heater load hardware;
5. wire, connectors, thermal interface material, fasteners, and enclosure material;
6. control PCB fabrication and components;
7. only then add bench instruments not already available;
8. add the shared programmable HBM accelerator when P1 work begins.

An open frame AC/DC supply needs its own suitable electrical enclosure or guarded installation so mains terminals are not exposed in normal use.

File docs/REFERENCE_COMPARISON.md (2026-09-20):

# Reference GPU Comparison

[Documentation index](README.md) · [Engineering specification](ENGINEERING_SPEC.md) · [Public sources](SOURCES.md)

**Reference date:** September 20, 2026

CGX 1 has no fabricated silicon. CGX figures below are architecture targets and arithmetic values, not benchmark measurements.

## Primary workstation reference

The primary shipping reference is NVIDIA RTX PRO 6000 Blackwell Workstation Edition.

| Specification | CGX 1 target | NVIDIA RTX PRO 6000 Blackwell Workstation Edition | Notes |
|---|---:|---:|---|
| Status | Engineering design | Shipping product | CGX has no fabricated ASIC |
| FP32 | 143.36 TFLOPS target | 125 TFLOPS published product figure | See NVIDIA product datasheet |
| GPU memory | 72 GB HBM4 baseline | 96 GB GDDR7 ECC | Different memory technologies |
| Future capacity target | 96 GB HBM4 | 96 GB GDDR7 ECC | CGX future target depends on 48 GB HBM4 stacks |
| Peak memory bandwidth | 6.6 TB/s target | 1.792 TB/s | Peak interface figures |
| Board power | 360 W nominal target | 600 W | Application efficiency is not implied |
| Card length | 167.5 mm target | 304.8 mm | CGX excludes external dock size |
| Card height | 68.5 mm target | 137.2 mm | CGX low profile board target |
| Slot class | Dual slot target | Dual slot | RTX PRO is extended height |
| Media engines | 4 encode + 4 decode target | 4 NVENC + 4 NVDEC | CGX media block is not implemented |
| Independent AI throughput | Not frozen | 4,000 FP4 AI TOPS published | No CGX TOPS claim |
| Independent RT throughput | Not frozen | 380 RT TFLOPS published | No CGX RT TFLOPS claim |

Arithmetic based on the published 125 TFLOPS product figure:

- CGX FP32 target is approximately **14.7% higher**.
- CGX peak memory bandwidth target is approximately **3.68×** the published 1.792 TB/s figure.
- CGX nominal board power target is **40% lower**.
- Peak FP32/W arithmetic is approximately **1.91×** the product specification ratio.
- CGX card length target is approximately **45% shorter**.
- CGX card height target is approximately **50% lower**.
- The rectangular card length × height envelope is approximately **27.4%** of the workstation card face envelope.

Those ratios do not predict frame rate, renderer time, local model performance, media throughput, compiler quality, driver maturity, or application performance.

### NVIDIA source discrepancy

NVIDIA currently publishes two official arithmetic presentations for this product. The workstation **product datasheet** lists **125 TFLOPS FP32 and 380 RT TFLOPS**. NVIDIA's RTX Blackwell architecture document lists **126.0 TFLOPS FP32 and 381.8 RT TFLOPS** for the same workstation configuration.

This repository uses the product datasheet figures in the comparison table so the baseline matches NVIDIA's product specification. Both official references are linked in [Public Sources](SOURCES.md).

## Secondary gaming reference

NVIDIA GeForce RTX 5090 remains a gaming reference. NVIDIA publishes:

- 21,760 CUDA cores;
- 32 GB GDDR7;
- 575 W total graphics power;
- 304 × 137 × 61 mm Founders Edition dimensions;
- approximately 104.8 TFLOPS peak FP32 in the RTX Blackwell architecture document.

The CGX target has more baseline memory, a higher peak memory bandwidth target, a lower nominal board power target, and a smaller card envelope. Actual gaming performance is unknown until a complete CGX graphics implementation, driver stack, and physical device exist.

## Software matters

Arithmetic throughput is only one part of GPU performance. A competitive implementation also requires compiler optimization, graphics APIs, shader compilation, scheduling, memory management, application compatibility, driver recovery, conformance, and workload specific tuning.

The implementation plan is documented in [Software Stack](SOFTWARE_STACK.md).

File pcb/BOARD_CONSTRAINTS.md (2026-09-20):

# PCB Constraints

[Documentation index](../docs/README.md) · [Engineering specification](../docs/ENGINEERING_SPEC.md) · [Electrical interface](../docs/ELECTRICAL_INTERFACE.md)

1. Board outline: 167.5 × 68.5 mm.
2. Installed thickness: no more than 39.5 mm outside the bracket zone.
3. High power and coolant services exit through the rear bracket.
4. Internal host cabling should not require more than 10 mm of side clearance beyond the card envelope.
5. ASIC/HBM package target: no larger than 55 × 55 mm.
6. Keep the package centroid close to the PCIe connector support region to control board stress.
7. PCIe Gen 6 routing requires complete channel simulation. Length matching alone is insufficient.
8. Separate sensitive reference clocks from multiphase switching nodes and fan/pump PWM paths.
9. Slot 12 V and external 48 V inputs require isolation so neither source can backfeed the other.
10. The board must boot with external 48 V absent.
11. External power presence must be hardware detectable before P3/P4 rails can enable.
12. The coolant flow interlock must directly participate in P3/P4 authorization.
13. Loss of external 48 V or valid coolant flow during P3/P4 must force the reference control path to P0 Safe Boot.
14. Provide rail test points and high speed compliance access on engineering boards.
15. Use replaceable bracket metalwork so one PCB can support low profile and full height installations.
16. Final stackup, via structure, copper weight, materials, impedance, spacing, and creepage require manufacturer and signal/power integrity signoff.

The selected 50 × 50 × 10 mm card fan volume and revised external dock packing are documented in [Mechanical Design](../docs/MECHANICAL_DESIGN.md).

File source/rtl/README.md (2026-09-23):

# RTL Scope

[Documentation index](../../docs/README.md) · [Matrix engine architecture](../../docs/MATRIX_ENGINE.md) · [Electrical interface](../../docs/ELECTRICAL_INTERFACE.md) · [Validation](../../docs/VALIDATION.md)

The public RTL currently contains twelve limited, separately testable boundaries:

- `cgx1_top.sv` covers board power-state gating and compute-tile enable behavior.
- `cgx1_matrix_pipeline_control.sv` covers matrix instruction legality, decode/capture/execute/writeback sequencing, VGPR address generation, source-release events, destination-complete events, 16-cycle reissue control, and matrix-to-matrix RAW/WAW interlocks against older pending destinations.
- `cgx1_matrix_operand_staging.sv` implements the 2 KB capture buffer and separate 2 KB active-execution operand set, with commit on capture cycle 7.
- `cgx1_matrix_wave_scoreboard.sv` tracks one wave's matrix source/destination VGPR reservations and reports ordinary-instruction RAW/WAW/WAR hazards plus matrix VGPR-port conflicts. Reservations use the pipeline controller's latched accepted register bases rather than live post-handshake issue inputs.
- `cgx1_matrix_result_staging.sv` implements the 1 KB eight-register output-result slot and returns one 1,024-bit wave register for each ordered writeback cycle.
- `cgx1_matrix_int8_execution.sv` implements the functional signed INT8 M16N16K32 arithmetic path over the frozen 16-cycle execution schedule.
- `cgx1_matrix_int8_path.sv` composes capture/active staging, opcode-6 INT8 execution, cycle-0 result bypass, result staging, and ordered writeback.
- `cgx1_matrix_int8_engine_shell.sv` wraps one controller, one per-wave scoreboard, and the INT8 path behind the external whole-wave VGPR interface; it accepts only opcode `0x6` at this boundary.
- `cgx1_matrix_resident_wave_arbiter.sv` selects parameterized resident-wave matrix requests with round-robin fairness.
- `cgx1_matrix_resident_wave_scoreboard.sv` routes per-wave reservation state and ordinary issue admission by resident-wave slot.
- `cgx1_resident_wave_vgpr_file.sv` implements the earlier parameterized per-slot logical VGPR storage boundary as eight modulo-8 bank classes.
- `cgx1_pooled_vgpr_mapper.sv` and `cgx1_pooled_vgpr_restore_mapper.sv` translate exact-count Active and sanitized-Reserved architectural VGPR accesses into pooled row/bank addresses.
- `cgx1_resident_wave_vgpr_allocator.sv` implements first-fit physical-row reservation, serialized round-robin validity invalidation, activation, and quiescent release.
- `cgx1_pooled_vgpr_storage.sv` implements pooled whole-wave data plus per-register validity, alias broadcast, bank-conflict rejection, and first-touch masked-write sanitization.
- `cgx1_matrix_vgpr_preflight.sv` and `cgx1_matrix_request_preflight_array.sv` gate legal matrix requests on exact allocation bounds and initialized operands without swallowing controller-owned illegal instructions.
- `cgx1_pooled_vgpr_matrix_subsystem.sv` composes allocation, restore, preflight, pooled storage, and matrix VGPR access arbitration.
- `cgx1_matrix_int8_resident_engine.sv` remains the resident-wave matrix control/arithmetic boundary with an external wave-tagged VGPR interface.
- `cgx1_matrix_int8_pooled_resident_engine.sv` connects that resident signed INT8 engine to the pooled VGPR subsystem.
- `cgx1_pooled_vgpr_ordinary_frontend.sv` maps ordinary vector source/destination VGPRs into the same exact-count pooled row/bank space.
- `cgx1_pooled_vgpr_ordinary_read_sequencer.sv` preserves one-cycle conflict-free reads and serializes distinct same-bank source pairs without exposing stale data.
- `cgx1_pooled_vgpr_shared_port_arbiter.sv` gives accepted matrix capture/writeback fixed-cycle priority while alternating contested ordinary/restore transfers.
- `cgx1_pooled_vgpr_execution_subsystem.sv` makes allocation, validity, storage, matrix traffic, ordinary traffic, restore, and release safety one shared authority.
- `cgx1_vector_int32_alu.sv` and `cgx1_vector_int32_pipeline.sv` implement the candidate wave32 INT32 ADD/SUB/AND/OR/XOR/SHL/LSR/ASR read-execute-writeback path.
- `cgx1_vector_resident_wave_scheduler.sv` and `cgx1_resident_vector_execution_frontend.sv` provide parameterized resident-wave vector selection and payload routing.
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

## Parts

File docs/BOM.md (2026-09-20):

# Architecture Bill of Materials

[Documentation index](README.md) · [Mechanical design](MECHANICAL_DESIGN.md) · [Electrical interface](ELECTRICAL_INTERFACE.md) · [Prototype procurement](PROTOTYPE_PROCUREMENT.md)

This is an architecture requirements BOM. Final manufacturer part numbers for custom silicon, PCB power stages, PHYs, connectors, and production cooling parts depend on implementation and validation.

## Custom silicon and package

- 4 × graphics compute chiplets on the selected process.
- 1 × central I/O and cache controller die.
- 2 × 36 GB HBM4 stacks for the 72 GB baseline.
- Package level SRAM/cache structure targeting 512 MB.
- Silicon interposer or equivalent advanced package substrate.
- Package lid or direct cold plate interface with controlled mounting pressure.

## PCB

- 167.5 × 68.5 mm low profile PCIe card.
- Approximately 16 to 20 HDI layers expected before final signal and power integrity work.
- Low loss material appropriate to the final PCIe channel target.
- Reinforced PCIe edge and package keepout.
- Backside stiffening under the package and high current regulator region.

## Power

- 48 V locking external DC connector rated above the continuous design current.
- Separate certified 48 V AC/DC supply, 10 A minimum and 12 A preferred.
- Multiphase 48 V intermediate conversion.
- Digital point of load control.
- High current integrated power stages selected against the final efficiency target.
- Hardware supervisor independent of normal GPU firmware.
- Voltage, current, and temperature telemetry.
- Input isolation that prevents slot and external rails from backfeeding each other.

See [Electrical Interface](ELECTRICAL_INTERFACE.md).

## Card cooling

| Item | Prototype reference | Purpose |
|---|---|---|
| Cold plate | Nickel plated copper hybrid cold plate target | Package to coolant heat transfer |
| Spreader | Vapor chamber or equivalent | Reduced power slot operation |
| Card fans | 2 × Same Sky CFM-5010B-170-361-22 | 50 × 50 × 10 mm PWM/tachometer airflow |
| Thermal interface | Replaceable paste/pad system | Package and regulator interfaces |
| Quick disconnects | Dry break pair | External supply and return |

## External thermal dock

| Item | Prototype reference | Purpose |
|---|---|---|
| Radiator | Corsair XR5 240 | 280 × 120 × 30 mm heat exchanger |
| Radiator fans | 2 × 120 mm pressure oriented PWM fans | Airflow through radiator |
| Pump/reservoir | Alphacool ES Reservoir DDCzero 1U, part 14571 | Compact combined pump and air volume |
| Flow sensor | To be selected | Measured interlock and telemetry |
| Coolant temperature sensors | To be selected | Inlet/outlet measurement |
| Bulk DC filtering | To be designed | Low voltage dock input conditioning |
| Dock enclosure | 310 × 210 × 75 mm target | Component packing and service clearance |

The 48 V AC/DC supply remains external to this enclosure.

## Display and board I/O

- 3 × Mini DisplayPort 2.1b connectors.
- 1 × USB C connector with DisplayPort Alt Mode target and ESD protection.
- service/debug connector.
- SPI flash for boot firmware.
- identity storage or secure element as required by the finished security design.

Detailed P0 purchasing tables are maintained in [Prototype Procurement](PROTOTYPE_PROCUREMENT.md).

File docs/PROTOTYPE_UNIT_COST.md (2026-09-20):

# Prototype Unit Cost Planning

[Documentation index](README.md) · [Procurement](PROTOTYPE_PROCUREMENT.md) · [Prototype build](PROTOTYPE_BUILD.md)

Prices are planning snapshots from September 20, 2026. Tax, shipping, fabrication setup charges, supplier changes, and replacement parts are not included.

## Cost after bench equipment is already owned

| Prototype configuration | Planning range | Included scope |
|---|---:|---|
| P0 thermal/mechanical card using an existing dock and bench | ~$200 to $300 | Card body, heater/cold plate hardware, wiring, consumed materials, carrier/control allowance |
| P0 active card using an existing dock | ~$300 to $450 | More complete control/power electronics plus card hardware |
| P0 complete system with dedicated thermal dock | **~$850 to $1,050** | Card plus separate 48 V supply, radiator, pump/reservoir, fans, plumbing, control hardware, and consumed materials |
| P1 bench with AMD Alveo U50 and dedicated dock | ~$3,450 to $3,700 | Shared programmable accelerator plus P0 class infrastructure |
| Additional P1 configuration reusing an existing dock | ~$3,050 to $3,250 | Accelerator and card side requirements while reusing dock hardware |

The revised complete P0 range reflects the selected Alphacool ES Reservoir DDCzero 1U pump/reservoir, currently about $199.99 in US retail listings, instead of the earlier generic pump allowance.

The programmable accelerator dominates P1 cost. The preferred development arrangement is one shared U50 class accelerator with multiple lower cost mechanical, thermal, and power prototypes.

## Shared test infrastructure

The first thermal program may use approximately $108 of cartridge heaters and a roughly $65 PCIe riser. These are test assets rather than parts that remain in every later card. Bench meters, scopes, inspection equipment, rework tools, and thermal instruments are also excluded from recurring unit cost once owned.

## Early custom hardware BOM range

A future 72 GB HBM4 custom device has a different cost structure. The following figures are **planning allowances, not supplier quotes**.

| Custom hardware category | Early planning range | Basis |
|---|---:|---|
| Custom GPU chiplets | ~$300 to $700 | Unquoted early device allowance |
| 72 GB HBM4 | ~$600 to $1,000 | Unquoted memory allowance |
| Advanced package/interposer | ~$250 to $500 | Unquoted package allowance |
| High layer count PCB | ~$75 to $150 | Low volume board allowance |
| VRM and power electronics | ~$80 to $150 | Low volume power allowance |
| Cooling plate and card mechanicals | ~$75 to $125 | Custom machining/mechanical allowance |
| Remaining electronics and connectors | ~$50 to $100 | Board support hardware |
| Assembly and test allocation | ~$50 to $100 | Low volume allowance |
| **Estimated hardware BOM** | **~$1,480 to $2,825** | **Not a manufacturing quote** |

This range excludes non recurring ASIC engineering, licensed IP, masks, tapeout, foundry qualification, advanced package NRE, production test development, driver engineering, and yield effects. HBM4 and advanced packaging can vary materially with volume and supplier agreements.

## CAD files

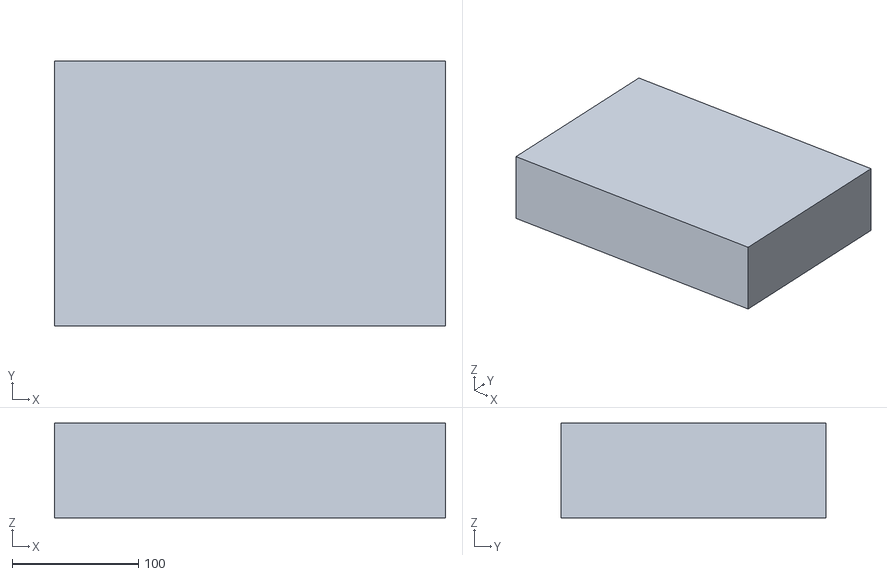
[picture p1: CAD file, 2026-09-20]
mechanical/cgx1_dock.stl
310.0 x 210.0 x 75.0

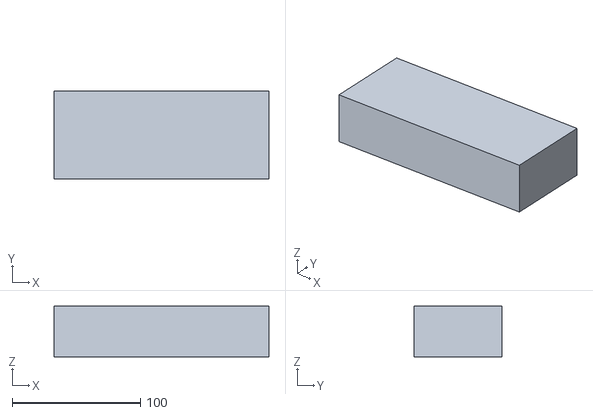
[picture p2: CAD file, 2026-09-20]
mechanical/cgx1_card.stl
167.5 x 68.5 x 39.5

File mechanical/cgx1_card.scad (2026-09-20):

// SPDX-License-Identifier: MIT
// Copyright (c) 2026 Brandon Connell
// CGX 1 low profile dual slot mechanical envelope, millimeters.
$fn = 48;

pcb_l = 167.5;
pcb_h = 68.5;
pcb_t = 1.6;
card_t = 39.5;

fan_d = 50.0;
fan_t = 10;
fin_z = 18.0;
fin_t = 11.0;
fan_z = fin_z + fin_t;

module card() {
    color("green") translate([0,0,8]) cube([pcb_l, pcb_h, pcb_t]);
    color("silver") translate([55,6.75,10]) cube([55,55,8]);
    color("gray",0.65) translate([4,2,fin_z]) cube([159.5,64.5,fin_t]);

    for (x=[38,105]) {
        color("black") translate([x,34.25,fan_z])
            cylinder(h=fan_t,d=fan_d,center=false);
    }

    color("gold") translate([18,-5,7]) cube([90,5,2]);
    color("lightgray") translate([-2,-6,0]) cube([2,80,card_t]);
    color("black") translate([-5,16,20]) rotate([0,90,0]) cylinder(h=8,d=8);
    color("black") translate([-5,31,20]) rotate([0,90,0]) cylinder(h=8,d=8);
}

card();

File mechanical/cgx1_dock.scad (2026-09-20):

// SPDX-License-Identifier: MIT
// Copyright (c) 2026 Brandon Connell
// CGX 1 external thermal dock packing model, millimeters.
$fn = 48;

dock_l = 310;
dock_w = 210;
dock_h = 75;
wall = 3;

radiator_l = 280;
radiator_w = 120;
radiator_t = 30;
fan_l = 120;
fan_w = 120;
fan_t = 25;

pump_l = 112;
pump_w = 57;
pump_h = 41.95;

module enclosure() {
    difference() {
        color("dimgray",0.25) cube([dock_l,dock_w,dock_h]);
        translate([wall,wall,wall])
            cube([dock_l-2*wall,dock_w-2*wall,dock_h-wall]);
    }
}

module components() {
    color("silver") translate([15,8,8])
        cube([radiator_l,radiator_w,radiator_t]);

    color("black",0.75) translate([22,8,38])
        cube([fan_l,fan_w,fan_t]);
    color("black",0.75) translate([153,8,38])
        cube([fan_l,fan_w,fan_t]);

    color("blue",0.65) translate([15,142,8])
        cube([pump_l,pump_w,pump_h]);

    color("orange",0.45) translate([145,142,8])
        cube([145,50,42]);
}

enclosure();
components();

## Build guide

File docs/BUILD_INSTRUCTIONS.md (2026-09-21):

# Production Build and Bring Up Instructions

[Documentation index](README.md) · [Engineering specification](ENGINEERING_SPEC.md) · [Software stack](SOFTWARE_STACK.md) · [Validation](VALIDATION.md)

This document describes the path from the public architecture package to custom GPU silicon. It does not replace foundry, package vendor, memory vendor, PCIe, electrical safety, or board manufacturing requirements.

## 1. Freeze interfaces

Define and verify:

- compute tile to I/O die fabric against [Chiplet Fabric](CHIPLET_FABRIC.md);
- HBM4 controller and PHY boundary;
- cache coherence behavior against the package directory model;
- command processor and queue ABI against [Scheduling and Preemption](SCHEDULING_PREEMPTION.md);
- PCIe BAR and address translation behavior against [Virtual Memory](VIRTUAL_MEMORY.md);
- shader execution against [ISA and Execution Model](ISA.md);
- matrix numeric behavior, tile shape, wave32 fragment mapping, register contract, capture/writeback schedule, modulo-8 bank-class placement, capture/active operand staging, cycle-0 output bypass, output-result staging, per-wave scoreboard behavior, signed INT8 arithmetic/path integration, one-wave INT8 engine-shell behavior, Matrix opcodes, reduction order, issue interval, and latency against [Matrix Engine Architecture](MATRIX_ENGINE.md);
- raster/texture/back-end behavior against [Graphics Pipeline](GRAPHICS_PIPELINE.md) and [Texture and Compression](TEXTURE_COMPRESSION.md);
- display and media block interfaces;
- firmware mailbox and telemetry registers;
- reset, power, fault, and recovery behavior against [Power Management](POWER_MANAGEMENT.md).

## 2. Implement and verify logic

1. Implement scalar/vector issue, register files, arithmetic, and matrix engines matching the frozen numeric, physical execution, and logical register-interface schedule contracts; then integrate load/store, texture, ray traversal, raster functions, and local caches.
2. Implement package fabric and coherent cache controllers.
3. Implement command processors, hardware queues, preemption, memory protection, and reset handling.
4. Implement the I/O-die power manager, tile clock gating, isolation, retention, and power-gating controls against [Power Management](POWER_MANAGEMENT.md).
5. Integrate licensed or independently verified high speed PHY and codec blocks where appropriate.
6. Build constrained random verification around interfaces and state transitions.
7. Add formal properties for deadlock freedom, coherence invariants, privilege boundaries, reset behavior, power sequencing, and fault containment.
8. Run compute, shader, memory, and command processor conformance workloads against pre silicon models.

The public SystemVerilog directory contains limited control/storage/arithmetic RTL for board power state behavior, matrix pipeline scheduling, matrix staging, per-wave VGPR hazard tracking, signed INT8 matrix execution, and a one-wave INT8 engine shell. It is not full GPU RTL. Run `./scripts/validate_rtl.sh` with Icarus Verilog installed to execute the current matrix control testbench.

## 3. Physical design

1. Select target process libraries and foundry PDK.
2. Partition compute tiles so long global timing paths do not cross tile boundaries unnecessarily.
3. Place global scheduling, HBM controllers, display/media, PCIe, security, and package cache coordination on the central I/O die.
4. Close the sustained clock target before qualifying the peak clock bin.
5. Complete static timing, IR drop, electromigration, power integrity, clock, thermal, DRC, LVS, DFT, and package bump signoff.
6. Use validation silicon where practical before committing the full package.

## 4. Package and PCB

1. Assemble compute tiles, I/O die, cache structure, and HBM stacks on the advanced package substrate.
2. Validate package warpage and cold plate mounting pressure.
3. Route the card within [PCB Constraints](../pcb/BOARD_CONSTRAINTS.md).
4. Simulate the complete PCIe channel including connector and package discontinuities.
5. Validate external power attach/detach behavior at the electrical boundary.
6. Populate engineering boards with current shunts, temperature probes, compliance access, and debug headers.

## 5. Cooling system

1. Machine the copper cold plate to cover compute and HBM heat sources.
2. Integrate the standalone spreading and fin path used for slot operation.
3. Pressure test the liquid assembly above expected pump head.
4. Leak test before installing electronics.
5. Validate actual loop flow through the final hose and quick disconnect assembly.
6. Tune radiator fan control against coolant and component temperature measurements.

Prototype dimensions and selected components are in [Mechanical Design](MECHANICAL_DESIGN.md).

## 6. Board bring up

1. Begin from P0 Safe Boot.
2. Validate auxiliary controller, SPI flash, telemetry, clocks, and reset tree.
3. Enumerate PCIe conservatively and increase link generation after signal validation.
4. Bring up one compute tile and HBM at reduced clocks.
5. Validate HBM training, ECC, and address behavior.
6. Enable compute tiles incrementally.
7. Validate external 48 V detection with high power rails disabled.
8. Attach the thermal dock and verify flow and temperature interlocks.
9. Enter P3 before attempting P4.
10. Remove external 48 V and verify fallback to P0 without increased slot demand.
11. Characterize each rail before performance work.
12. Characterize tile V/F points, gating transitions, retention behavior, and hysteresis before enabling automatic performance policy.

## 7. Driver bring up

Follow [Software Stack](SOFTWARE_STACK.md):

1. Linux PCIe enumeration and memory management;
2. reset, interrupts, command submission, fences, faults, telemetry;
3. Vulkan compute;
4. rasterization, depth, texture, presentation;
5. shader compiler expansion;
6. ray tracing;
7. media APIs;
8. Windows display/compute stack;
9. Direct3D 12.

## 8. Manufacturing acceptance

Each production candidate needs traceable results for:

- power rail limits and efficiency;
- PCIe compliance;
- HBM training and error handling;
- display outputs;
- compute and graphics correctness;
- media encode/decode correctness;
- thermal soak;
- fault interlocks;
- dock attach/detach behavior;
- firmware update and recovery;
- driver reset and recovery;
- mechanical fit and mounting pressure.

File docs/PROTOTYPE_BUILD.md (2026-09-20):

# Prototype Build Plan

[Documentation index](README.md) · [Mechanical design](MECHANICAL_DESIGN.md) · [Electrical interface](ELECTRICAL_INTERFACE.md) · [Procurement](PROTOTYPE_PROCUREMENT.md) · [Test record](TEST_RECORD_TEMPLATE.md)

## P0: electrothermal card and dock

P0 uses the final card envelope and revised external dock architecture while replacing the custom GPU package heat source with controlled electrical heaters.

P0 validates:

- 167.5 × 68.5 × 39.5 mm card packaging;
- selected 50 × 50 × 10 mm card fan volume;
- low profile and full height bracket concepts;
- rear coolant and low voltage power service routing;
- 48 V dock distribution;
- 310 × 210 × 75 mm dock packing;
- 240 mm radiator and two 120 mm fan fit;
- pump/reservoir fit and service access;
- approximately 360 W sustained thermal load handling;
- coolant flow and temperature measurement;
- fault interlocks;
- firmware power state behavior;
- host slot fit through a PCIe mechanical test card or inactive carrier.

A machined copper spreader should place heater load beneath the regions assigned to the future compute and HBM package. Instrument the spreader, coolant inlet/outlet, regulator region, external input, host slot input, and ambient air.

## P1: programmable compute surrogate

P1 adds a shared HBM capable programmable accelerator to the development bench. AMD Alveo U50 remains the reference surrogate because the production card provides a compact 75 W PCIe form factor, 8 GB HBM2, and programmable logic.

P1 can exercise:

- PCIe host software;
- HBM traffic patterns;
- firmware and telemetry protocols;
- command queue concepts;
- memory movement;
- early compute compiler/API work;
- RTL blocks that fit the selected FPGA.

P1 does not reproduce CGX 1 performance, package topology, 72 GB HBM4 capacity, or the complete graphics pipeline.

## P0 mechanical sequence

1. Build the card shroud, bracket fixtures, and dock enclosure from the repository CAD dimensions.
2. Fabricate a 167.5 × 68.5 mm carrier PCB or dimensional board with the intended PCIe edge and mounting geometry.
3. Install two actual 50 × 50 × 10 mm card fans or exact dimensional surrogates.
4. Machine a copper spreader/cold plate test assembly covering the planned package region.
5. Install controllable resistive heat sources with independent temperature sensing.
6. Install coolant fittings at the rear bracket and connect the dry break hose set.
7. Install the Corsair XR5 240 radiator reference or exact dimensional equivalent in the dock.
8. Install two 120 mm radiator fans.
9. Install the Alphacool ES Reservoir DDCzero 1U pump/reservoir or exact dimensional equivalent.
10. Install coolant flow and temperature sensing.
11. Connect a separate certified 48 V AC/DC supply to the low voltage dock input.
12. Leak test without powered electronics.
13. Bring thermal load up in controlled steps while logging temperature, flow, electrical input, and coolant rise.

## P0 electrical sequence

1. Validate the auxiliary control supply at low power.
2. Validate voltage and current sensors against bench measurements.
3. Verify that P3/P4 cannot be entered without external 48 V.
4. Verify that P3/P4 cannot be entered without valid coolant flow.
5. Verify P0, P1, P2, P3, and P4 board limits with an electronic or resistive load.
6. Verify docked host slot draw stays at or below 25 W.
7. While in P3/P4, remove external 48 V and verify immediate fallback to P0 rather than P2.
8. While in P3/P4, invalidate coolant flow and verify immediate fallback to P0.
9. Validate hardware fault and temperature fault response.
10. Validate rail sequencing before attaching a programmable compute surrogate.

## P0 acceptance targets

| Measurement | Initial target | Evidence required |
|---|---:|---|
| Full thermal load | 360 W sustained | Logged load and duration |
| Coolant flow | ≥ 1.5 L/min nominal | Calibrated flow measurement |
| Bulk coolant rise at 360 W | ≈ 3.45 °C analytical reference | Measured inlet/outlet temperatures |
| Simulated junction estimate at 35 °C ambient | < 85 °C target | Sensor placement and thermal record |
| Dock mode host slot draw | ≤ 25 W | Measured voltage/current |
| Dock fault fallback | P0 / 25 W | State log and slot power trace |
| External input | 48 V nominal | Measured voltage/current |
| Dock packing | No interference | Closed enclosure inspection and dimensions |

Use [Test Record Template](TEST_RECORD_TEMPLATE.md) for measured results.

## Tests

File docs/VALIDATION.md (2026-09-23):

# Validation Plan

[Documentation index](README.md) · [Project status](STATUS.md) · [Test record template](TEST_RECORD_TEMPLATE.md) · [Repository integrity](REPOSITORY_INTEGRITY.md)

Validation is separated by evidence category so a calculation cannot be mistaken for a physical measurement.

## 1. Repository validation

The repository gate checks:

- public wording policy;
- negative controls proving the wording gate rejects prohibited test cases;
- private machine paths and local residue;
- secrets and signing material patterns;
- PowerShell 5.1 parse compatibility;
- external GitHub Actions pinned to full commit hashes;
- shared design value consistency;
- local Markdown links;
- C and C++ build success;
- executable firmware, analytical-model, ISA-reference, matrix-numeric, matrix-architecture, matrix-pipeline-schedule, matrix-banking, matrix-staging, matrix-result-staging, matrix-scoreboard, matrix-INT8-execution, matrix-INT8-path, matrix-INT8-engine-shell, matrix-INT8-resident-engine, resident-wave-VGPR-storage, pooled-VGPR lifecycle/reference, and power-management policy tests. The RTL workflow also compiles and executes pooled restore-mapping, matrix-preflight, allocator, storage, matrix-frontend, pooled-subsystem, and pooled-resident-INT8 testbenches.

## 2. Analytical model

The C++ model verifies:

- FP32 arithmetic from lanes and clock;
- low profile card envelope;
- coolant temperature rise from power and flow;
- analytical junction estimate from stated thermal resistance targets;
- FP32 per watt arithmetic;
- SIMD partition-to-lane consistency;
- texture-block totals and peak bilinear sampler arithmetic;
- raster-partition and ROP-lane totals;
- chiplet-fabric read-bandwidth budget relative to HBM4;
- queue/priorities and preferred VRAM page constants;
- L1/shared, tile-L2, aggregate-L2, and package-cache consistency.

The analytical model does not produce application speedup claims.

## 3. ISA reference

The executable ISA test verifies:

- base 32-bit field encode/decode round trip;
- instruction-class recognition;
- scalar register bounds;
- full 8-bit vector register addressing.

This validates the public field contract only. It is not a shader core or ISA conformance suite.

## 4. Matrix numeric reference

The executable matrix test verifies:

- the four-matrix-engine-per-CU and native wave32 architecture constants;
- accepted FP16, BF16, OCP FP8 E4M3/E5M2, and signed INT8 precision tuples;
- rejection of unsupported and invalid tuples;
- OCP FP8 special values, subnormals, round-to-nearest ties-to-even conversion, and both saturation modes;
- exhaustive finite positive and negative FP8 encode/decode round trips for E4M3 and E5M2;
- BF16 round-to-nearest ties-to-even conversion;
- exact FP16/BF16/FP8 widening to FP32 and FP32 fused multiply-add reference behavior;
- signed INT8 to signed INT32 accumulation with defined modulo overflow behavior;
- explicit absence of TF32, FP64 matrix, FP32-input matrix, OCP MX, and structured-sparsity claims.

The separate matrix-architecture executable test verifies M16N16K16 and M16N16K32 shapes, exact wave32 fragment coverage, input packing, VGPR grouping/alignment/overlap rules, Matrix opcode validity, the 8/16/8 capture-execute-writeback schedule, 16-cycle issue interval, 33-cycle result latency, fixed per-instruction reduction order, and dense arithmetic-rate derivation.

The matrix-pipeline executable test verifies that one wave32 VGPR transfer is 1,024 bits; the input staging budget is 2,048 bytes; capture reads exactly A0-A3, B0-B3, and C/D0-C/D7; writeback covers D0-D7; source registers remain protected through capture; the destination remains pending through writeback; and a steady stream issued every 16 cycles stays within two whole-wave reads or one whole-wave write per cycle without requiring simultaneous matrix read/write access. It also validates matrix-to-matrix pending-destination dependency detection, including exhaustive comparison of every legal non-aliased matrix register layout against every aligned pending D/C range.

The matrix-banking executable test verifies eight modulo-8 bank classes, A base class 0, distinct B base class 4, exact A/B alias broadcast, C/D bank separation, and exhaustively checks every valid destination/A/B base-register combination for capture-cycle conflicts under a single-matrix-access-per-bank-class rule.

The matrix-staging executable test verifies the 2,048-byte capture set, separate 2,048-byte active execution operand set, ordered eight-cycle capture, cycle-7 commit, and preservation of the active set while the next capture is incomplete.

The matrix-result-staging executable test verifies the 1,024-byte eight-register result slot, rejection of a second load while occupied, ordered writeback cycles 0 through 7, release after the final cycle, safe slot reuse, and cycle-0 load-to-writeback bypass.

The matrix-INT8-execution executable test verifies M16N16K32 signed INT8 arithmetic over 16 execution cycles, canonical A/B/C/D fragment mapping, two K terms per output per cycle, the frozen even/odd signed INT32 reduction order, signed extreme inputs, and explicit modulo-`2^32` overflow.

The matrix-INT8-path executable test composes capture-to-active operand staging, the 16-cycle signed INT8 execution model, cycle-0 result bypass, and ordered result drain. The corresponding SystemVerilog integration testbench models the wave register file and performs a complete opcode-6 capture/execute/writeback transaction; that integrated path has passed RTL CI.

The matrix-INT8-engine-shell SystemVerilog testbench adds the controller and per-wave scoreboard around that path, rejects a non-INT8 matrix opcode, models the external 256-entry whole-wave VGPR namespace, verifies source and destination hazard reporting, and checks a complete opcode-`0x6` result transaction. The single-engine INT8 shell has passed the repository RTL simulation gate.

The matrix-INT8-resident-engine SystemVerilog testbench uses a four-slot test configuration of the parameterized resident-wave boundary. It checks round-robin selection, wave-tagged VGPR traffic, identical VGPR-number independence across waves, same-wave pending-destination blocking, per-wave ordinary RAW admission, wave-tagged writeback, and invalid full-wave request tagging. Four slots is a test configuration, not a frozen architecture count. The test also exercises a dependency-stalled request across a missed issue slot and verifies that the next accepted request preserves the 16-cycle matrix cadence without simultaneous matrix VGPR read/write traffic. The resident-engine boundary has passed the repository RTL simulation gate.

The resident-wave VGPR storage SystemVerilog testbench exercises a four-slot parameterization of an eight-bank, 32-row-per-bank organization. It verifies two whole-wave reads, one whole-wave write, modulo-8 bank placement for canonical A/B and adjacent C/D accesses, exact source alias broadcast, independent storage for identical architectural VGPR numbers in different resident waves, and canonical lane order on the 1,024-bit delivery buses. Four slots is a test configuration rather than a frozen occupancy target. Exact-revision simulation evidence remains false until this candidate passes RTL CI.

The matrix-scoreboard executable test verifies a 256-VGPR per-wave reservation state, all single-register ordinary RAW/WAW/WAR outcomes across the full register namespace, source release, destination completion, multiple independent pending destinations, exact A/B alias handling, and read/write-port conflict reporting. The RTL integration test additionally changes the live issue register inputs after acceptance and verifies that scoreboard state is created from the controller-latched accepted bases.

These references validate the architecture contract and functional reference behavior. The standalone signed INT8 arithmetic RTL has passed the repository simulation gate. The composed INT8 path has its own exact-revision simulation evidence flag. None of these tests establish physical VGPR macros, timing closure, area/power characterization, compiler integration, or measured silicon performance.

The mixed resident execution frontend has a dedicated executable admission reference and SystemVerilog integration test. The test covers pooled initialization, resident vector execution/writeback, release blocking while vector execution is live, matrix blocking on a live vector destination hazard, recovery after that hazard clears, and same-edge matrix/vector acceptance exclusion. The external per-wave vector dependency-ready input remains a scheduler contract rather than evidence of a completed compute-unit scheduler.

## 5. Power-management reference

The executable power-management test verifies:

- unchanged 25/45/70/220/360 W board limits;
- P3/P4 dock-state classification;
- P0-P4 maximum tile operating classes;
- scheduler eligibility only for executable tile states;
- rejection of invalid board/tile-state values and negative, non-finite, and over-limit budget requests;
- rejection of combined plans that violate either tile-state caps or the active board budget;
- exact-limit budget acceptance;
- exhaustive rejection of skipped orderly tile-state transitions;
- voltage-before-frequency ordering for performance increases;
- frequency-before-voltage ordering for performance decreases;
- scheduler-drain and dirty-coherence guards before orderly idle/retention/off transitions;
- coherence-ready guards before wake reaches Idle or becomes scheduler eligible;
- emergency isolation conditions for hardware, thermal, dock-power, and coolant faults;
- configurable promotion/demotion hysteresis behavior.

The policy model does not claim a measured tile power, regulator response time, transition latency, or silicon V/F curve.

## 6. Firmware

Reference firmware tests cover:

- P0 through P4 board limits;
- external 48 V required for P3/P4;
- valid coolant flow required for P3/P4;
- dock loss fallback to P0;
- coolant flow loss fallback to P0;
- hardware fault fallback to P0;
- high GPU temperature fallback;
- high VRM temperature fallback;
- invalid requested state fallback.

The dock fault tests also verify that the fallback does not request a 70 W slot state.

## 7. RTL boundary

The public RTL currently covers top-level power-state/tile-enable behavior, matrix pipeline control, capture/active operand staging, output-result staging, signed INT8 arithmetic/path, one-wave hazard reporting, parameterized resident-wave matrix arbitration, wave-local dependency handling, per-wave scoreboard routing, and ordinary issue admission. FP16/BF16/FP8 arithmetic, physical resident-wave VGPR/storage macros, ordinary vector execution, and the rest of the GPU pipeline remain open.

RTL simulation is run with Icarus Verilog in SystemVerilog 2012 mode through `scripts/validate_rtl.sh`. The Ubuntu RTL CI workflow runs for every push to `main`, preventing a final reference, schema, or truth-state revision from escaping exact-revision RTL validation. Functional unit and integration testbenches do not replace constrained-random verification, formal work, synthesis, FPGA/emulation, timing closure, or physical implementation.

The critical architecture contracts are defined in [ISA](ISA.md), [Graphics Pipeline](GRAPHICS_PIPELINE.md), [Texture and Compression](TEXTURE_COMPRESSION.md), [Chiplet Fabric](CHIPLET_FABRIC.md), [Virtual Memory](VIRTUAL_MEMORY.md), and [Scheduling and Preemption](SCHEDULING_PREEMPTION.md). RTL must match those contracts or update them and their tests in the same revision.

The power state scaffold must keep the reported state and tile enable state consistent. A dock fault reports P0 and disables compute tiles.

## 8. Mechanical validation

Before P0 acceptance:

- verify 167.5 × 68.5 mm PCB dimensions;
- verify 39.5 mm installed card thickness;
- verify selected 50 × 50 × 10 mm card fan fit;
- verify both bracket variants;
- verify the 310 × 210 × 75 mm dock enclosure;
- verify 280 × 120 × 30 mm radiator fit;
- verify two 120 × 25 mm radiator fan volumes;
- verify 112 × 57 × 41.95 mm pump/reservoir volume;
- verify fitting, hose, wiring, and enclosure wall clearance;
- verify coolant and power services clear the chassis rear boundary;
- inspect mounting pressure and PCB bending;
- pressure and leak test the cooling assembly.

## 9. P0 electrothermal validation

P0 measures:

- 360 W sustained heat removal;
- coolant inlet/outlet temperature;
- actual loop flow;
- cold plate and simulated package temperatures;
- external 48 V current and voltage;
- host slot current in dock mode;
- regulator and connector temperatures;
- fan and pump speed;
- external 48 V loss response;
- coolant flow loss response.

Use [Test Record Template](TEST_RECORD_TEMPLATE.md) for each repeatable configuration.

## 10. P1 surrogate validation

P1 results must identify the surrogate hardware. Alveo U50 measurements cannot be labeled as CGX performance.

P1 can provide evidence for:

- host PCIe software;
- memory traffic experiments;
- telemetry protocols;
- queue and command concepts;
- selected RTL blocks;
- early compiler/API experiments.

## 11. Future silicon validation

A fabricated CGX device requires separate evidence for:

- PCIe compliance and signal integrity;
- HBM training, ECC, sustained bandwidth, and error handling;
- compute instruction correctness;
- matrix precision, conversion, accumulation, capability enumeration, frozen tile/fragment/opcode behavior, register-file delivery, issue timing, RTL timing closure, area/power, throughput validation, and compiler lowering;
- graphics API conformance;
- shader/compiler correctness;
- raster and depth/stencil correctness;
- ray tracing correctness;
- media codec correctness;
- display timing and link compliance;
- power and transient behavior;
- per-tile DVFS characterization, transition ordering, gating/retention correctness, hysteresis stability, and emergency isolation;
- thermal characterization;
- reset and fault recovery;
- long duration workloads;
- application and game compatibility.

## 12. Reporting results

Every published result should identify whether it is:

- a target;
- analytical;
- simulated;
- measured on P0;
- measured on P1 surrogate hardware;
- measured on engineering silicon;
- measured on production silicon.

A calculation does not replace a hardware measurement, and surrogate hardware does not establish CGX application performance.

The executable matrix test set now also includes ordinary/shared pooled-VGPR and resident INT32 vector execution/scheduling references. The RTL workflow includes ordinary/shared arbitration, same-bank read sequencing, vector INT32 ALU/pipeline, resident vector scheduling, and unified pooled execution-subsystem behavioral tests. These tests establish logical behavior only; they do not establish timing, area, power, or silicon performance.

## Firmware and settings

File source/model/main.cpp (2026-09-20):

// SPDX-License-Identifier: MIT
// Copyright (c) 2026 Brandon Connell
#include "model.hpp"

#include <iomanip>
#include <iostream>

int main()
{
    using namespace cgx1;

    const CardGeometry card{kTargetLengthMm, kTargetHeightMm, kTargetThicknessMm};
    const ThermalInputs thermal{360.0, 1.5, 35.0, 0.085, 0.040};

    std::cout << std::fixed << std::setprecision(2);
    std::cout << "CGX 1 analytical engineering model\n\n";
    std::cout << "Peak FP32 target: " << Fp32PeakTflops(kTargetFp32Lanes, kTargetPeakClockGhz) << " TFLOPS\n";
    std::cout << "Peak memory bandwidth target: " << kTargetMemoryTbps << " TB/s\n";
    std::cout << "Native wave size: " << kNativeWaveSize << " lanes\n";
    std::cout << "Texture block target: " << kTextureBlocksTotal << "\n";
    std::cout << "Peak bilinear sampler arithmetic: "
              << TexturePeakGtex(kTextureBlocksTotal, kBilinearSamplesPerTextureBlockPerCycle, kTargetPeakClockGhz)
              << " Gsamples/s\n";
    std::cout << "Fabric read bandwidth budget: " << kFabricAggregateReadTbps << " TB/s\n";
    std::cout << "VRAM baseline: " << kTargetVramGb << " GB\n";
    std::cout << "Board power target: " << kTargetBoardPowerWatts << " W\n";
    std::cout << "Peak FP32 per watt arithmetic: " << PeakFp32PerWatt(kTargetPeakFp32Tflops, kTargetBoardPowerWatts) << " TFLOPS/W\n";
    std::cout << "Card envelope passes target: " << (FitsTargetEnvelope(card) ? "YES" : "NO") << "\n";
    std::cout << "Coolant rise at 1.5 L/min: " << CoolantRiseC(360.0, 1.5) << " C\n";
    std::cout << "Estimated junction at 35 C ambient: " << EstimatedJunctionC(thermal) << " C\n\n";
    std::cout << "These values are analytical design targets. No fabricated CGX 1 silicon measurement is represented.\n";
    return 0;
}

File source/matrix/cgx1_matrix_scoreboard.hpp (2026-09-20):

// SPDX-License-Identifier: MIT
// Copyright (c) 2026 Brandon Connell
#pragma once

#include "cgx1_matrix_pipeline.hpp"

#include <array>
#include <cstdint>
#include <stdexcept>

namespace cgx1::matrix {

inline constexpr std::uint32_t kMatrixScoreboardRegisterCount = 256U;

using MatrixRegisterMask =
    std::array<bool, kMatrixScoreboardRegisterCount>;

struct MatrixWaveScoreboardState
{
    MatrixRegisterMask sourcePending{};
    MatrixRegisterMask destinationPending{};
};

struct MatrixOrdinaryIssueRequest
{
    MatrixRegisterMask readMask{};
    MatrixRegisterMask writeMask{};
    bool usesReadPorts = false;
    bool usesWritePort = false;
};

struct MatrixOrdinaryIssueStatus
{
    bool rawHazard = false;
    bool wawHazard = false;
    bool warHazard = false;
    bool readPortConflict = false;
    bool writePortConflict = false;

    constexpr bool Ready() const
    {
        return !rawHazard
            && !wawHazard
            && !warHazard
            && !readPortConflict
            && !writePortConflict;
    }
};

inline MatrixRegisterMask MatrixRegisterRangeMask(
    std::uint8_t base,
    std::uint32_t count)
{
    if (count == 0U
        || static_cast<std::uint32_t>(base) + count
            > kMatrixScoreboardRegisterCount)
    {
        throw std::invalid_argument("matrix scoreboard register range is invalid");
    }

    MatrixRegisterMask mask{};
    for (std::uint32_t offset = 0U; offset < count; ++offset)
    {
        mask[static_cast<std::uint32_t>(base) + offset] = true;
    }
    return mask;
}

inline bool MatrixMaskAny(const MatrixRegisterMask& mask)
{
    for (bool bit : mask)
    {
        if (bit)
        {
            return true;
        }
    }
    return false;
}

inline bool MatrixMasksOverlap(
    const MatrixRegisterMask& left,
    const MatrixRegisterMask& right)
{
    for (std::uint32_t index = 0U;
         index < kMatrixScoreboardRegisterCount;
         ++index)
    {
        if (left[index] && right[index])
        {
            return true;
        }
    }
    return false;
}

inline void MatrixMaskSet(
    MatrixRegisterMask& destination,
    const MatrixRegisterMask& source)
{
    for (std::uint32_t index = 0U;
         index < kMatrixScoreboardRegisterCount;
         ++index)
    {
        destination[index] = destination[index] || source[index];
    }
}

inline void MatrixMaskClear(
    MatrixRegisterMask& destination,
    const MatrixRegisterMask& source)
{
    for (std::uint32_t index = 0U;
         index < kMatrixScoreboardRegisterCount;
         ++index)
    {
        if (source[index])
        {
            destination[index] = false;
        }
    }
}

inline void ReserveMatrixWaveScoreboard(
    MatrixWaveScoreboardState& state,
    std::uint8_t destinationBase,
    std::uint8_t sourceABase,
    std::uint8_t sourceBBase)
{
    if (!IsValidMatrixRegisterLayout(
            destinationBase,
            sourceABase,
            sourceBBase))
    {
        throw std::invalid_argument("matrix scoreboard issue layout is invalid");
    }

    if (MatrixMaskAny(state.sourcePending))
    {
        throw std::logic_error(
            "matrix scoreboard source capture is already active");
    }


    const MatrixRegisterMask sourceA =
        MatrixRegisterRangeMask(
            sourceABase,
            kMatrixSourceRegistersPerLane);
    const MatrixRegisterMask sourceB =
        MatrixRegisterRangeMask(
            sourceBBase,
            kMatrixSourceRegistersPerLane);
    const MatrixRegisterMask destination =
        MatrixRegisterRangeMask(
            destinationBase,
            kMatrixAccumulatorRegistersPerLane);

    if (MatrixMasksOverlap(sourceA, state.destinationPending)
        || MatrixMasksOverlap(sourceB, state.destinationPending)
        || MatrixMasksOverlap(destination, state.destinationPending))
    {
        throw std::logic_error(
            "matrix scoreboard issue depends on a pending destination");
    }

    MatrixMaskSet(state.sourcePending, sourceA);
    MatrixMaskSet(state.sourcePending, sourceB);
    MatrixMaskSet(state.destinationPending, destination);
}

inline void ReleaseMatrixWaveSources(
    MatrixWaveScoreboardState& state,
    std::uint8_t sourceABase,
    std::uint8_t sourceBBase)
{
    MatrixMaskClear(
        state.sourcePending,
        MatrixRegisterRangeMask(
            sourceABase,
            kMatrixSourceRegistersPerLane));
    MatrixMaskClear(
        state.sourcePending,
        MatrixRegisterRangeMask(
            sourceBBase,
            kMatrixSourceRegistersPerLane));
}

inline void CompleteMatrixWaveDestination(
    MatrixWaveScoreboardState& state,
    std::uint8_t destinationBase)
{
    MatrixMaskClear(
        state.destinationPending,
        MatrixRegisterRangeMask(
            destinationBase,
            kMatrixAccumulatorRegistersPerLane));
}
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

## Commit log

2026-09-20 CGX 1 engineering design
    [cgx1_card.scad, cgx1_card.stl, cgx1_dock.scad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]
2026-09-20 Tighten architecture audit findings
2026-09-20 Define per-tile power management architecture
2026-09-21 Preserve matrix issue cadence after dependency stalls
2026-09-21 Wire pooled VGPR RTL validation contract
2026-09-21 Fix pooled subsystem testbench keyword portability
    [cgx1_pooled_vgpr_matrix_subsystem_tb.sv]
2026-09-23 Wire ordinary vector execution validation
2026-09-24 Reduce pooled INT8 integration simulation footprint
2026-09-24 Fix mixed-workload admission test handshake timing
    [cgx1_ordinary_shared_control_tb.sv]
2026-09-24 Wire pooled execution restore service test signals
2026-09-24 Fix pooled execution restore test sequencing
    [cgx1_pooled_vgpr_execution_subsystem_tb.sv]
2026-09-24 Materialize pooled VGPR mapper metadata signals
